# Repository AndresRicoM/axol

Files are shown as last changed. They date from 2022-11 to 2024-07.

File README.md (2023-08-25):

<div align="center">
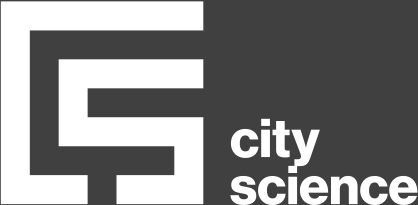
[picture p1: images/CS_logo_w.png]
      
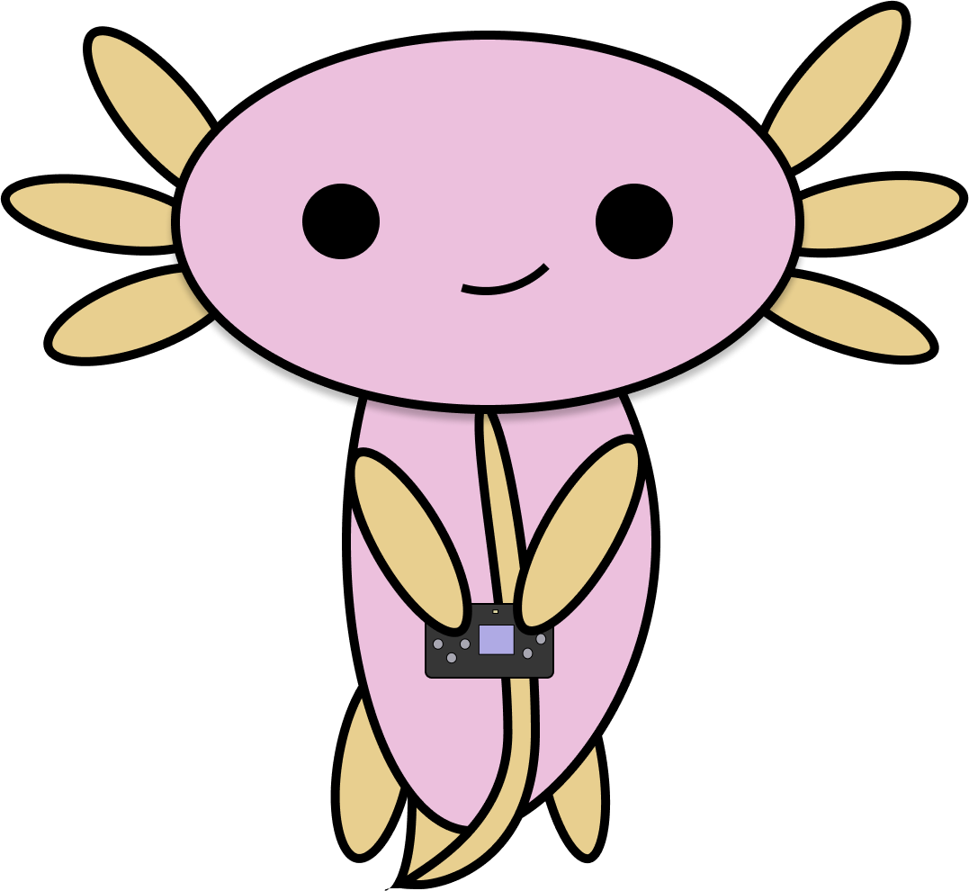
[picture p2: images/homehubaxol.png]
      <br>
      <a href="https://github.com/AndresRicoM/axol/blob/main/LICENSE.MD">
            
      </a>

</div><br><br><br>

<h1> axol </h1>

Sensors for granular assessment of water usage patterns in informal settlements.

This repository contains all files needed to replicate a fully functional Axol sensing system.

The current version of the system is has four sensor types and a HomeHub communication device. The four sensing units include tank sensors, bucket sensors, quality sensors and environmental sensors.

Andres Rico - MIT Media Lab - <aricom@mit.edu>

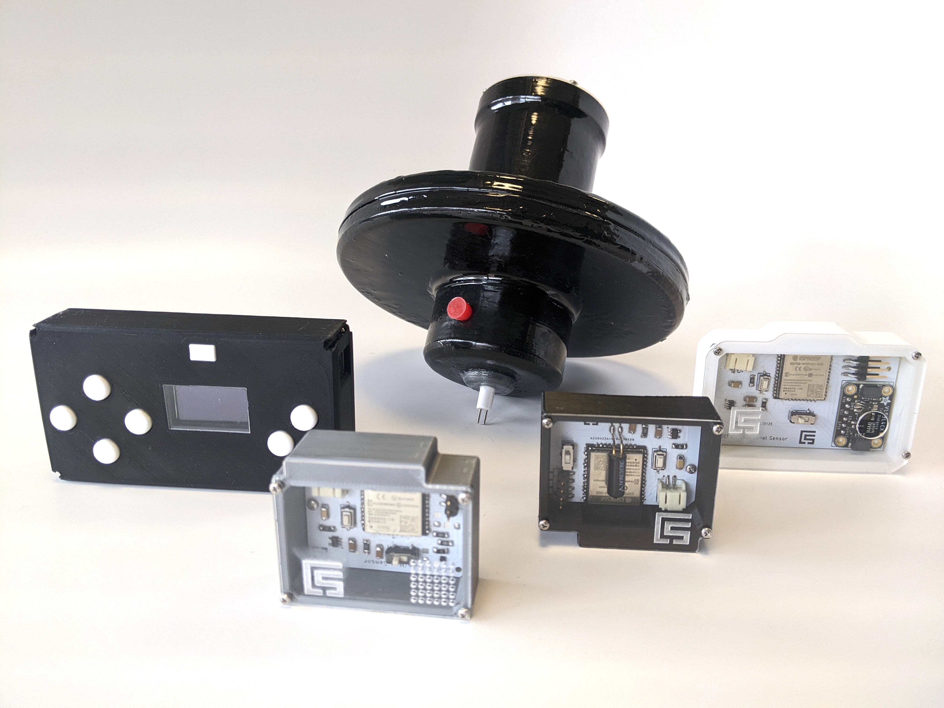
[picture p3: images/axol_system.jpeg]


<h1>Devices</h1>

<h2><a href="https://github.com/AndresRicoM/axol/tree/main/homehub">HomeHub</a></h2>
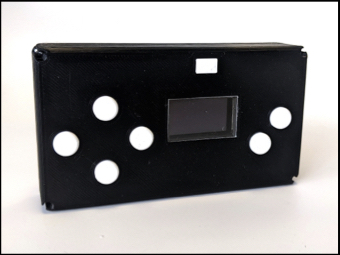
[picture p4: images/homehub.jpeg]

The HomeHub acts as a user interface and as the centralized data relay for the system. All of the sensing units send the data directly to a HomeHub. The HomeHub formats and sends the infroamtion to a remote database. 

Note: It is advised to firstly manufacture a HomeHub device as all other sensors directly connect to the HomeHub. 

<h2><a href="https://github.com/AndresRicoM/axol/tree/main/sensors/tank_sensor">Tank Sensor</a></h2>

<p align="left">
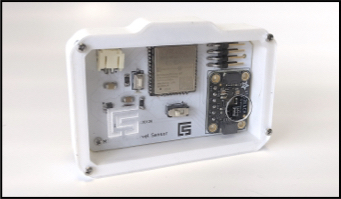
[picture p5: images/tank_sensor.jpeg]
      
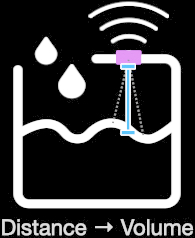
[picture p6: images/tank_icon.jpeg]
      
</p>

The tank sensor uses Adafruits VXL ToF distance sensor. It measures the distance between a water tanks lid and the water line. With this information we can calculate a containers used volume to detemrine how much water is stored within the container. 

<h2><a href="https://github.com/AndresRicoM/axol/tree/main/sensors/bucket_sensor">Bucket Sensor</a></h2>
<p align="left">
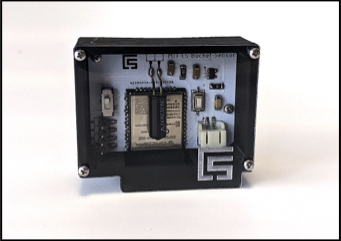
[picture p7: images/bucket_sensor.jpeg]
      
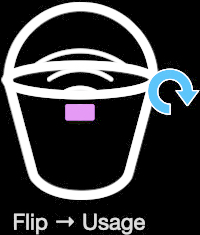
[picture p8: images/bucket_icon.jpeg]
      
</p>

The bucket sensor uses a simple tilt switch. The switch is closed whenever a bucket is flipped. Everytime that the switch is activated, the sensor sends a notice to the HomeHub and the HomeHub timestamps the information before sending it to the database. 

<h2><a href="https://github.com/AndresRicoM/axol/tree/main/sensors/water_quality_sensor">Quality Sensor</a></h2>

<p align="left">
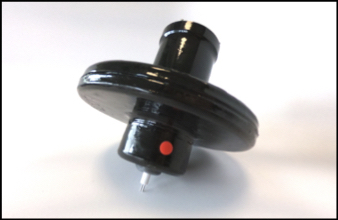
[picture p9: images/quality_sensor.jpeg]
      
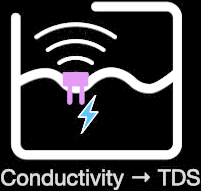
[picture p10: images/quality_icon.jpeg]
      
</p>

The quality sensor measures EC in water to get an estimate of Total Dissolved Solids. 

<h2>Environmental Sensor</h2>
The environmental sensor uses an STH sensor to measure enviroenmental temperature and humidity. The sensor can be a good way to evaluate system and battery performance. It can also be used to track environemetal variables of places were the other sensors are placed. 

<h1>Programming Devices</h1>

Devices can be easily programmed using the [Arduino IDE](https://www.arduino.cc/en/software). You will need to make sure that you have the Espressif [ESP32 core](https://github.com/espressif/arduino-esp32) installed along with all required libraries. 

We need a [USB-TTL adapter](https://duckduckgo.com/?q=USB-TTL+adapter&atb=v313-1&iax=images&ia=images) to program the sensor. 

- Connect Cables as Follows:

```
Device - Adapter
V+   ------ 3.3V (or 5V)
GND  ------ GND
TX   ------ RX
RX   ------ TX
```

NOTE: MAKE SURE TO DISCONNECT ANY POWER SUPPLY. THE BOARD SHOULD ONLY BE POWERED BY THE ADAPTER CABLES. 
NOTE: EACH DEVICE HAS A DIFFERENT PIN ORDER, REFERENCE EACH DEVICE'S PIN DIAGRAM TO MAKE SURE YOU ARE CONNECTING PINS CORRECTLY. 

- Once connection is done, open your serial monitor at a 115200 baud rate, click the reset button on the device and verify that you see inforamtion. 
- Set ESP to Boot Mode. To set the device on bootmode, press the reset button
- Upload sketch 
- Reset device. Toggle switch to opposite position and presss the reset button. 

<h1>Device Registration</h1>

Each device needs to be individually registered. You can register all devices [here](http://blindspot.media.mit.edu/homehubweb/registration.html). 

All sensors must be paired with a HomeHub that has been previously registered. 

<h1>Querying Data</h1>

All system data can be queried through available [API calls](https://github.com/AndresRicoM/axol/wiki/API-Documentation). The calls allow you to get information on network status as well as to access all data for all registered sensors. You will need to firstly register a HomeHub as your HomeHub's Mac Add will act as your key to access all of your systems data.

<h1>Viewing your system's data </h1>

All sensors send their information to the HomeHub, the HomeHub then sends it into a database for storage, calculation of water volumes and consumption and visualization. 

You can check your systems data [here](http://blindspot.media.mit.edu/homehubweb/status_check.html)
By just typing in your HomeHubs registered MAC address. 

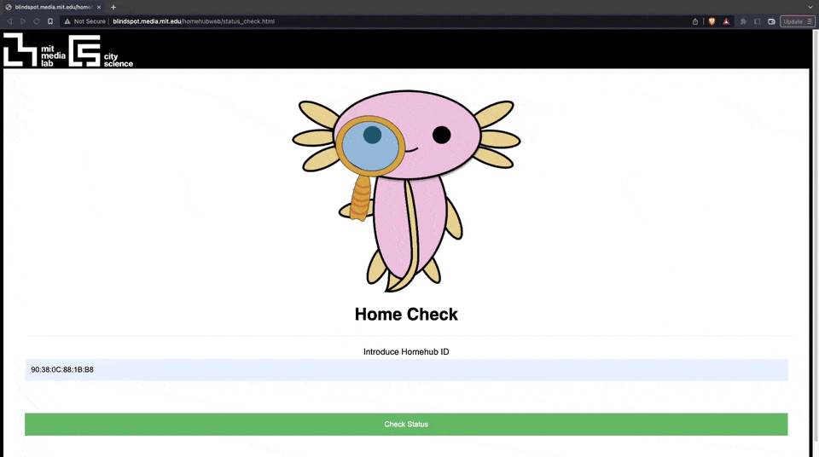
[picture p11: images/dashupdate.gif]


NOTE: ONLY REGISTERED HOMEHUBS WILL ALLOW TO SEE DATA IN THIS DASHBOARD

<h1>Data handling</h1>

The system uses the HomeHub to send data to a server hosted @MIT. All of the data of registered devices is accessible by the developers of the platform. If you do not want developers to have access you will need to build backend infrstructure that will allow you to save data in a different server and modify the 
   connect_send() 
   get_system_stats()
   server_send() 
   
function in the HomeHub's <a href="https://github.com/AndresRicoM/axol/blob/main/homehub/code/cs_homehub.ino">code</a>.

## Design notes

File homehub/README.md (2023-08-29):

# AXOL

```
   █████╗ ██╗  ██╗ ██████╗ ██╗     
  ██╔══██╗╚██╗██╔╝██╔═══██╗██║     
  ███████║ ╚███╔╝ ██║   ██║██║     
  ██╔══██║ ██╔██╗ ██║   ██║██║     
  ██║  ██║██╔╝ ██╗╚██████╔╝███████╗
  ╚═╝  ╚═╝╚═╝  ╚═╝ ╚═════╝ ╚══════╝

  ᓬ(• - •)ᕒ

Andres Rico - MIT Media Lab - <aricom@mit.edu>

```

<h1>Homehub </h1>

<h2>Program Set-up</h2>
You will need to add your wifi credentials to the program. The device needs an SSID and a password. If the network is open. You can leave the password as an emptu string. 
Modify the following lines:

```
  //WIFI Variables
  const char* ssid = ""; //Change accordingly to connect to a WIFi network.
  const char* password = "";

```

You will also need to add your OpenWeather API key. If you do not have one, you can get a free key [here](https://openweathermap.org/api).
Add yout key in the following line:

```
  In the 

  get_complete_weather()

  fucntion, modify line:

  //Open Weather API Key
  const String key = "{Your Open Weather API Key}";

```

After modifying these lines, you are ready to upload the program to your device.

<h2>Bill Of Materials</h2>

```
quantity - component - estimated price

1 - ESP32-WROOM-32E-H4 - $3.15
1 - Switch (JS102011JCQN) - $0.65
1 - Button (PTS636 SM25F SMTR LFS) - $0.14140
1 - 0.1 uF Capacitor (C1206C104KARAC7800) - $0.14880	
1 - 1uF Capacitor (C3216X7R1H105K160AB) - $0.09680	
1 - 10uF Capacitor (GRT31CC8YA106ME01L) - $0.20060	
1 - Gikfun Metal Ball Tilt Shaking Position Switches - $0.399
1 - 500 mAh Lipo Battery 1578 - $7.95000	
1 - Battery Connector (S2B-PH-SM4-TB(LF)(SN)) - $0.41040	
1 - 3.3V Voltage Regulator (RT9080-33GJ5) - $0.25780	
1 - 4 POS Headers (GBC36SGSN-M89) - $0.47
1 - 10K Ohm Resistor (RC1206FR-0710KL) - $0.02

```

<h2>PCB Diagram</h2>

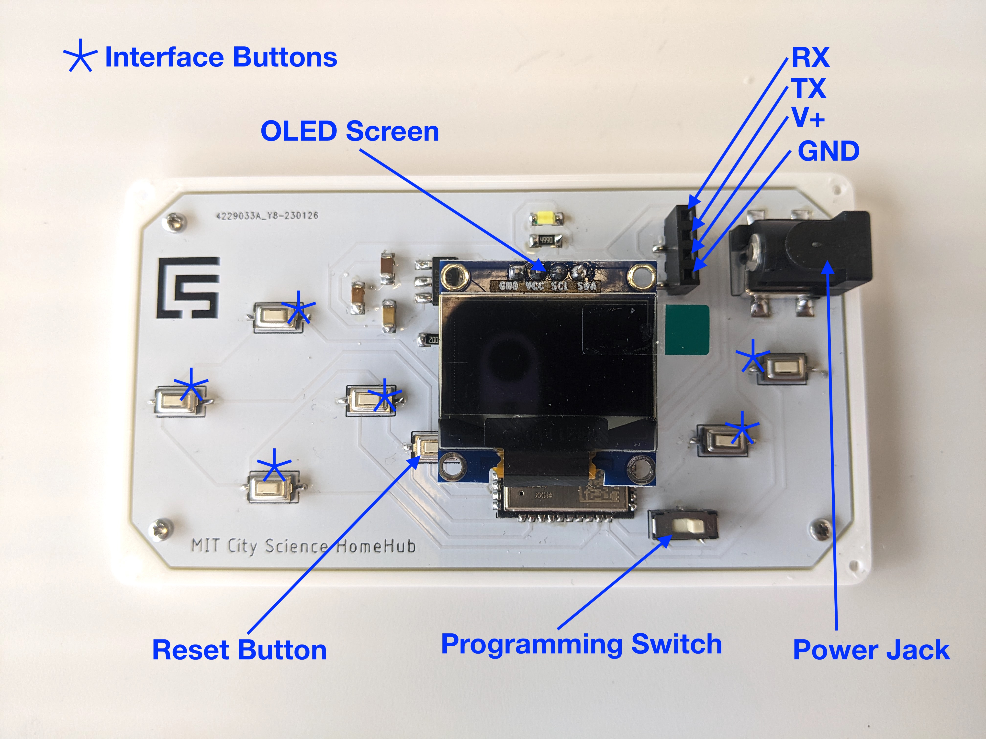
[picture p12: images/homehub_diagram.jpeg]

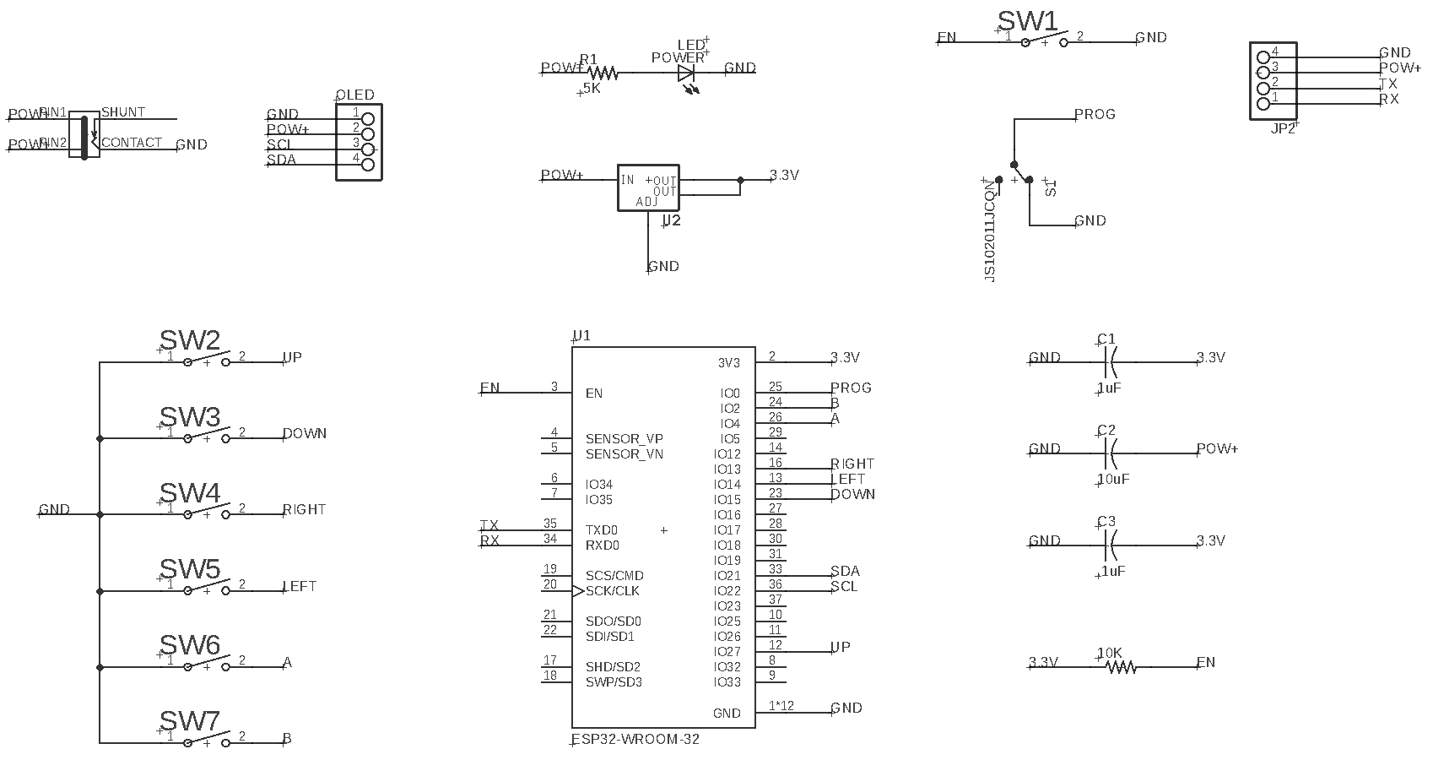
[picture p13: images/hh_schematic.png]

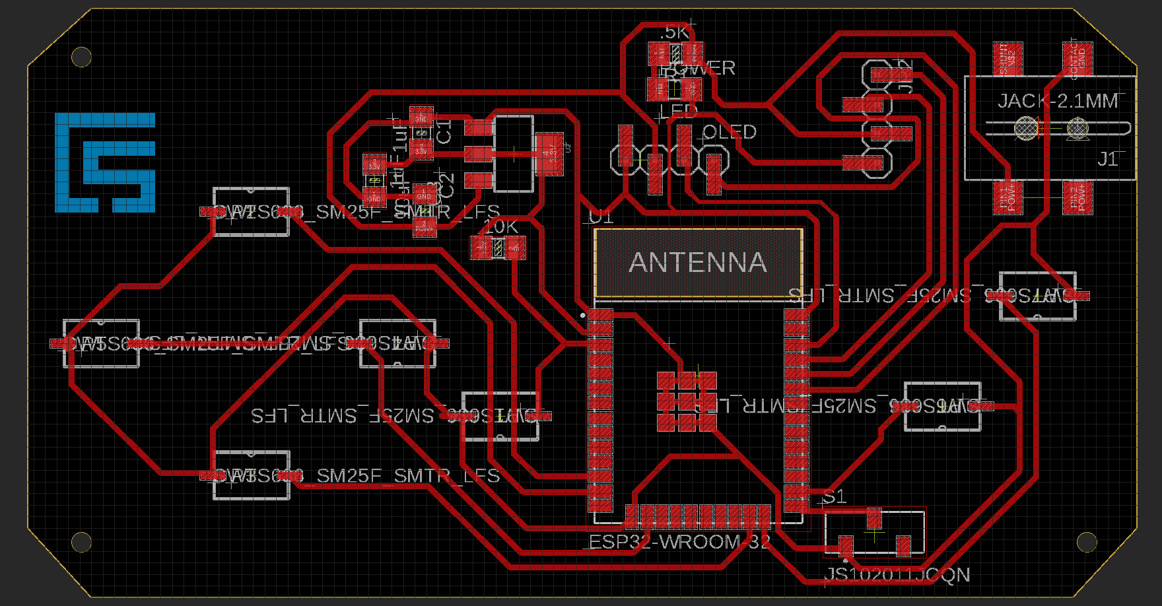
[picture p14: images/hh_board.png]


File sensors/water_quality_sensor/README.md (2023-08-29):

# AXOL

```
   █████╗ ██╗  ██╗ ██████╗ ██╗     
  ██╔══██╗╚██╗██╔╝██╔═══██╗██║     
  ███████║ ╚███╔╝ ██║   ██║██║     
  ██╔══██║ ██╔██╗ ██║   ██║██║     
  ██║  ██║██╔╝ ██╗╚██████╔╝███████╗
  ╚═╝  ╚═╝╚═╝  ╚═╝ ╚═════╝ ╚══════╝

  ᓬ(• - •)ᕒ

Andres Rico - MIT Media Lab - <aricom@mit.edu>

```

<h1>Quality Sensor </h1>

<h2>Program Set-up</h2>

You will need to add your wifi credentials to the program. The device only needs an SSID for esp32 to activate. You do not need a password. Make sure that the SSID provided is the same as the one provided to you HomeHub. The devices need to be connected to the same network. To add SSID modify the following line:

```
  constexpr char WIFI_SSID[] = ""; //Network name, no password required.

```

You will also need to add the mac address of the HomeHub that the sensor will send its data to. To add the mac address modify the following line: 

Substitute each 00 pair with the specific digits of the Homehubs mac address.

```
  //Receiver address
  uint8_t broadcastAddress[] = {0x00, 0x00, 0x00, 0x00, 0x00, 0x00}; //MAC Address for receiving homehub.

```

After modifying these lines, you are ready to upload the program to your device.

<h2>Bill Of Materials</h2>

```
quantity - component - estimated price

1 - ESP32-WROOM-32E-H4 - $3.15
1 - Switch (JS102011JCQN) - $0.65
1 - Button (PTS636 SM25F SMTR LFS) - $0.14140
1 - 500 mAh Lipo Battery 1578 - $7.95000	
3 - 10K Ohm Resistor (RC1206FR-0710KL) - $0.02
1 - 7 POS Headers (GBC36SGSN-M89) - $0.8225
2 - 0 Ohm Resistor (RC1206JR-070RL) - $0.02040	
1 - Temp/Hum Sensor (SHT40I-AD1B-R3) - $2.45700	
1 - Battery Connector (S2B-PH-SM4-TB(LF)(SN)) - $0.41040	
1 - KEYESTUDIO TDS Meter Probe Water - $13.99

```

<h2>PCB Diagram</h2>

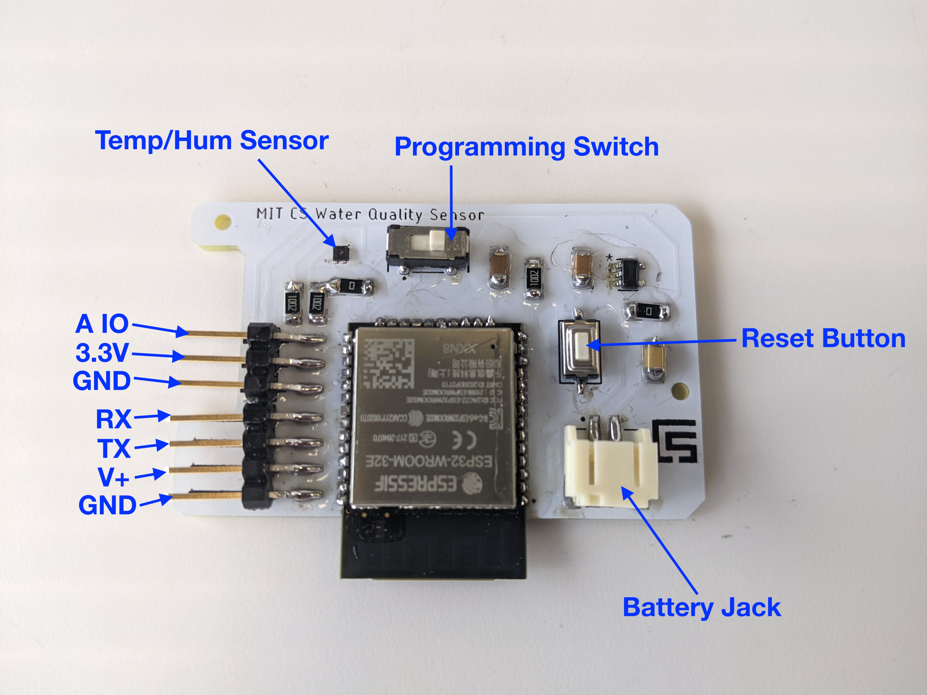
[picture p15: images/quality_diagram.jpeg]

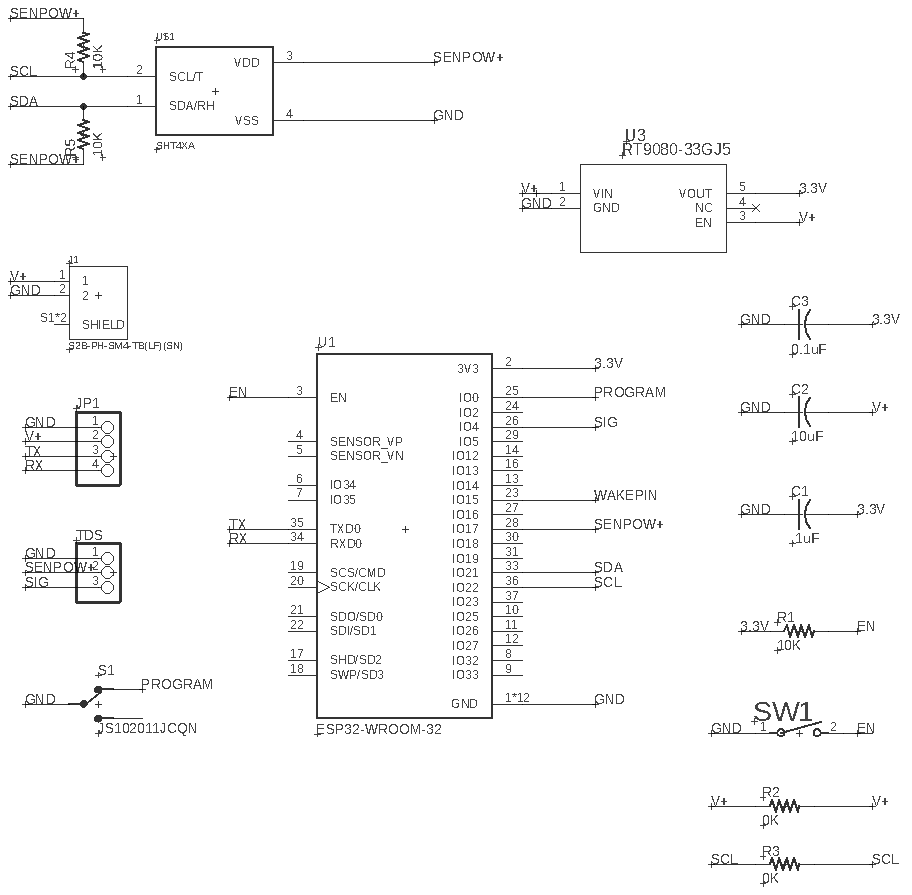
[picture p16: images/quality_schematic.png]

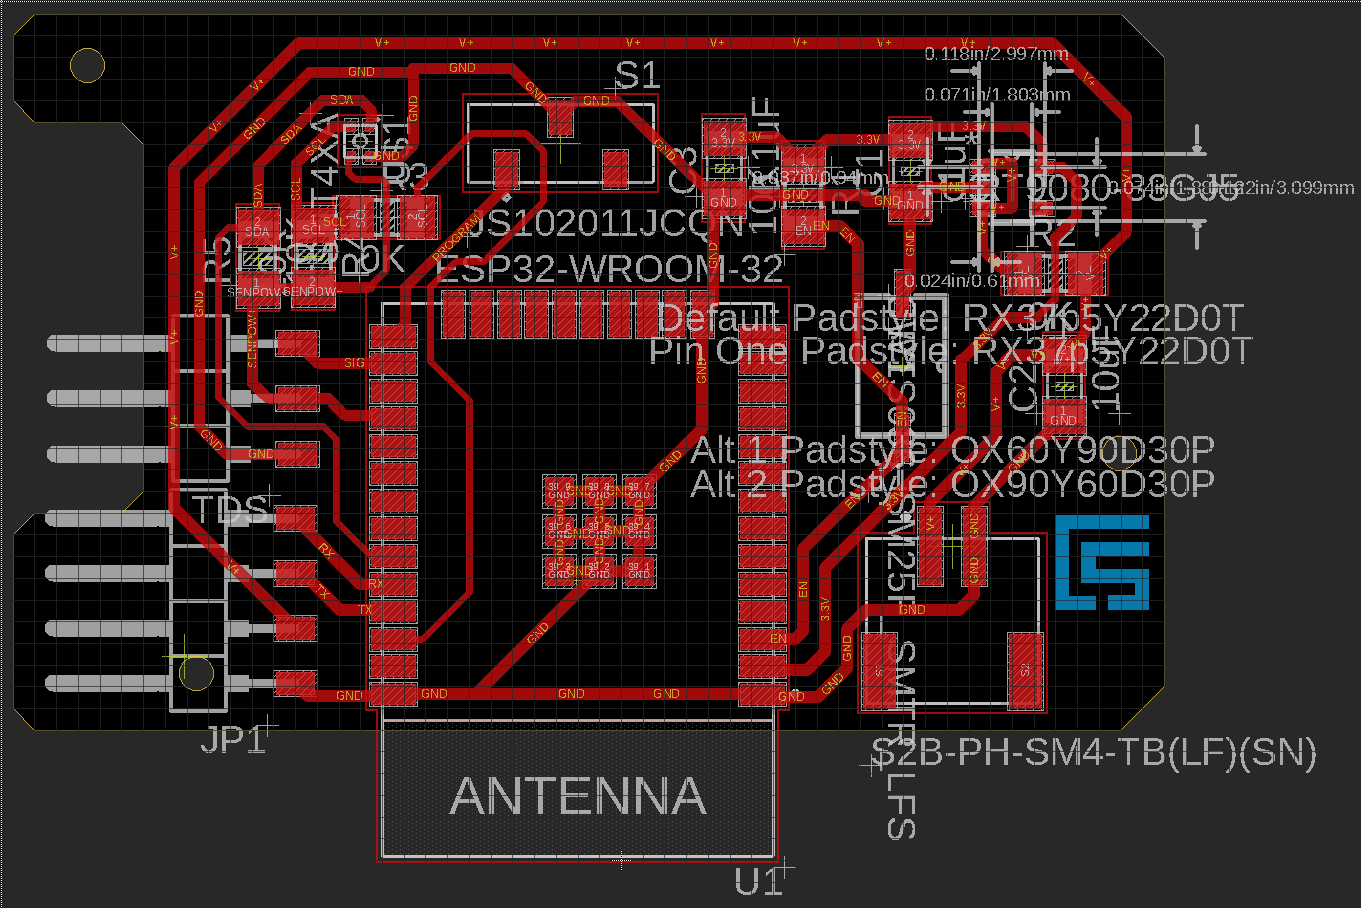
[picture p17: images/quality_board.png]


<h2>Demos</h2>



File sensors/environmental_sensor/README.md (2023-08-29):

# AXOL

```
   █████╗ ██╗  ██╗ ██████╗ ██╗     
  ██╔══██╗╚██╗██╔╝██╔═══██╗██║     
  ███████║ ╚███╔╝ ██║   ██║██║     
  ██╔══██║ ██╔██╗ ██║   ██║██║     
  ██║  ██║██╔╝ ██╗╚██████╔╝███████╗
  ╚═╝  ╚═╝╚═╝  ╚═╝ ╚═════╝ ╚══════╝

  ᓬ(• - •)ᕒ

Andres Rico - MIT Media Lab - <aricom@mit.edu>

```

<h1>Environmental Sensor </h1>

<h2>Program Set-up</h2>

You will need to add your wifi credentials to the program. The device only needs an SSID for esp32 to activate. You do not need a password. Make sure that the SSID provided is the same as the one provided to you HomeHub. The devices need to be connected to the same network. To add SSID modify the following line:

```
  constexpr char WIFI_SSID[] = ""; //Network name, no password required.

```

You will also need to add the mac address of the HomeHub that the sensor will send its data to. To add the mac address modify the following line: 

Substitute each 00 pair with the specific digits of the Homehubs mac address.

```
  //Receiver address
  uint8_t broadcastAddress[] = {0x00, 0x00, 0x00, 0x00, 0x00, 0x00}; //MAC Address for receiving homehub.

```

After modifying these lines, you are ready to upload the program to your device.

<h2>Bill Of Materials</h2>

```
quantity - component - estimated price

1 - ESP32-WROOM-32E-H4 - $3.15
1 - Switch (JS102011JCQN) - $0.65
1 - Button (PTS636 SM25F SMTR LFS) - $0.14140
1 - 500 mAh Lipo Battery 1578 - $7.95000	
1 - Temp/Hum Sensor (SHT40I-AD1B-R3) - $2.45700	
3 - 10K Ohm Resistor (RC1206FR-0710KL) - $0.02
1 - Battery Connector (S2B-PH-SM4-TB(LF)(SN)) - $0.41040	
1 - Temp/Hum Sensor (SHT40I-AD1B-R3) - $2.45700	

```

<h2>PCB Diagram</h2>


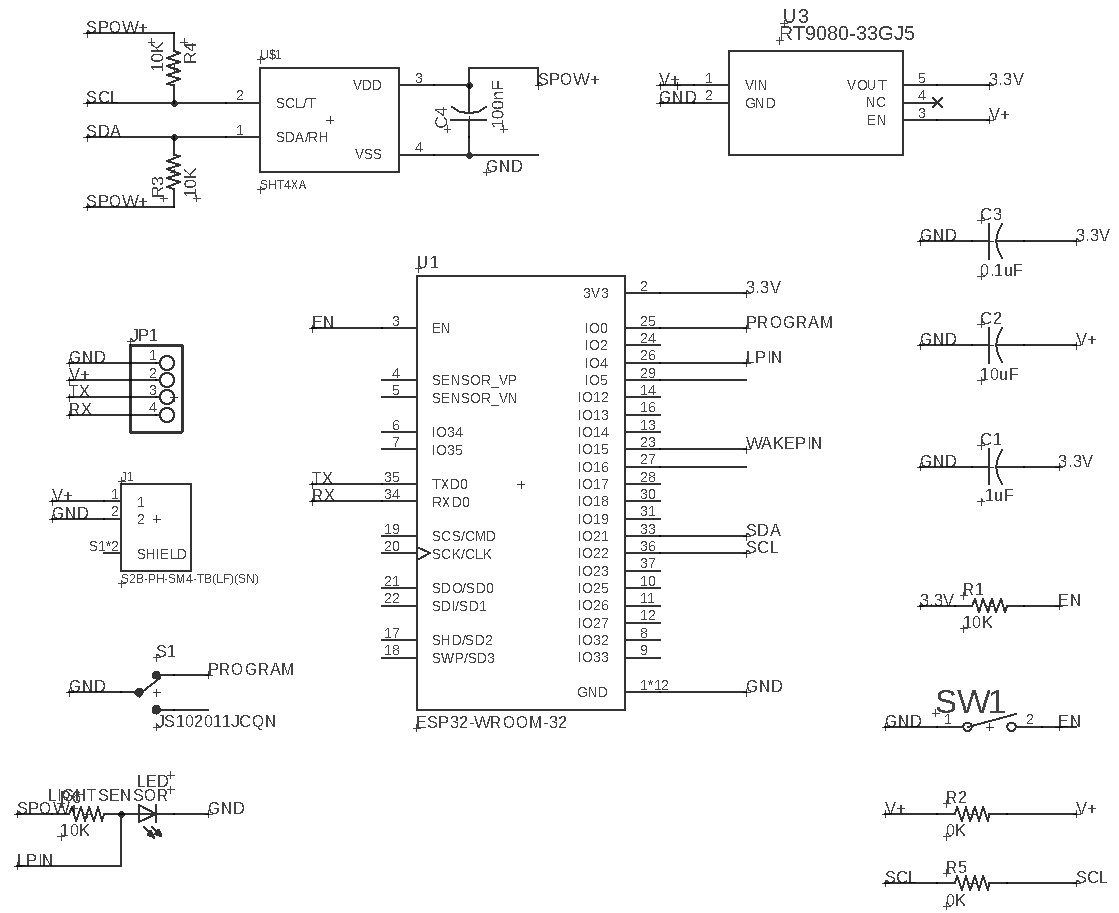
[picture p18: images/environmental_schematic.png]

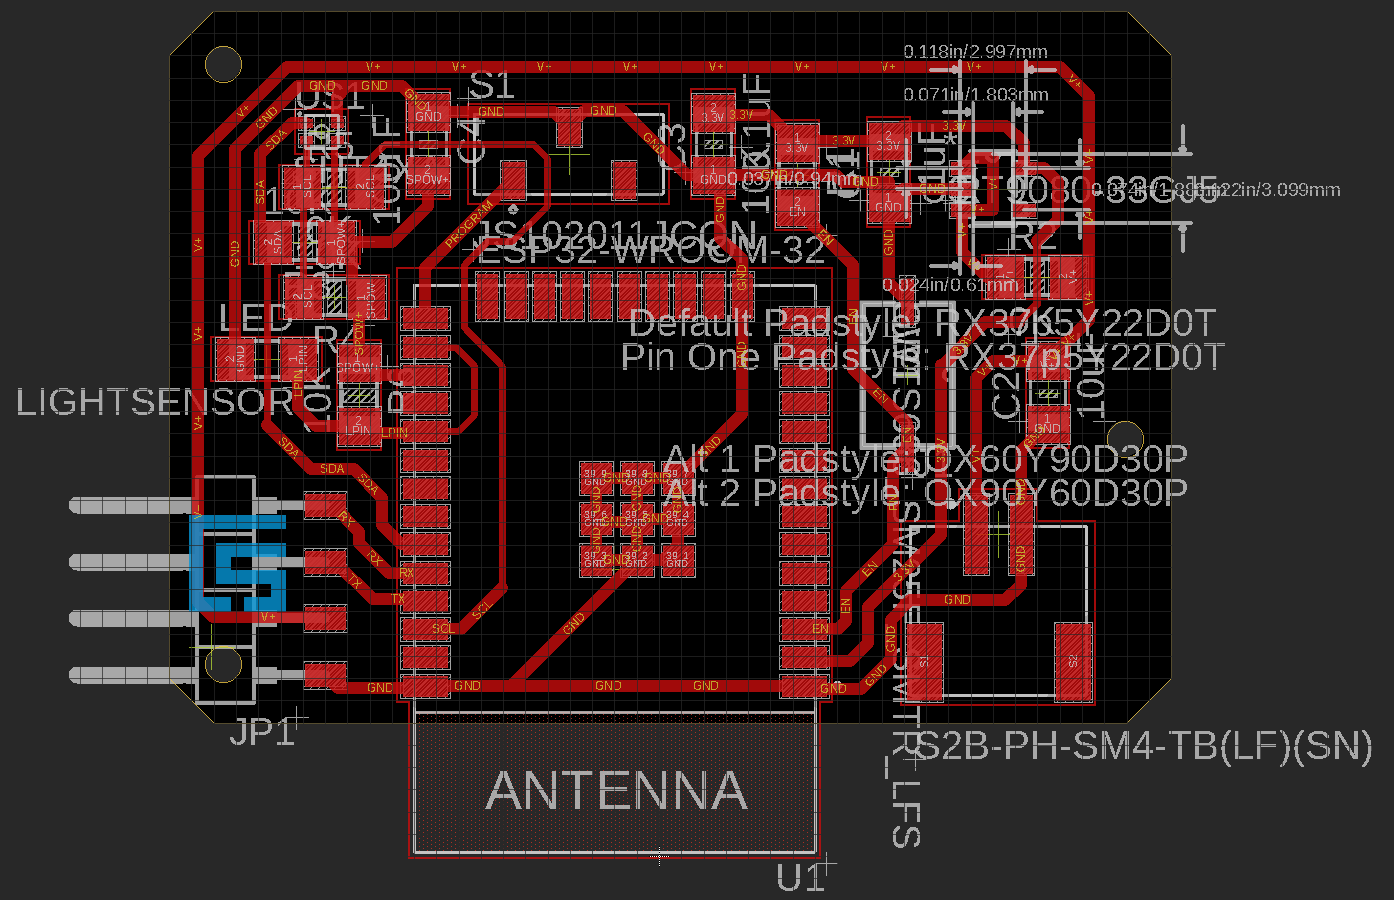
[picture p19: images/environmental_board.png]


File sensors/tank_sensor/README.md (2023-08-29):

# AXOL

```
   █████╗ ██╗  ██╗ ██████╗ ██╗     
  ██╔══██╗╚██╗██╔╝██╔═══██╗██║     
  ███████║ ╚███╔╝ ██║   ██║██║     
  ██╔══██║ ██╔██╗ ██║   ██║██║     
  ██║  ██║██╔╝ ██╗╚██████╔╝███████╗
  ╚═╝  ╚═╝╚═╝  ╚═╝ ╚═════╝ ╚══════╝

  ᓬ(• - •)ᕒ

Andres Rico - MIT Media Lab - <aricom@mit.edu>

```

<h1>Tank Sensor </h1>

<h2>Program Set-up</h2>

You will need to add your wifi credentials to the program. The device only needs an SSID for esp32 to activate. You do not need a password. Make sure that the SSID provided is the same as the one provided to you HomeHub. The devices need to be connected to the same network. To add SSID modify the following line:

```
  constexpr char WIFI_SSID[] = ""; //Network name, no password required.

```

You will also need to add the mac address of the HomeHub that the sensor will send its data to. To add the mac address modify the following line: 

Substitute each 00 pair with the specific digits of the Homehubs mac address.

```
  //Receiver address
  uint8_t broadcastAddress[] = {0x00, 0x00, 0x00, 0x00, 0x00, 0x00}; //MAC Address for receiving homehub.

```

After modifying these lines, you are ready to upload the program to your device.

<h2>Bill Of Materials</h2>

```
quantity - component - estimated price

1 - ESP32-WROOM-32E-H4 - $3.15
1 - Switch (JS102011JCQN) - $0.65
1 - Button (PTS636 SM25F SMTR LFS) - $0.14140
1 - 500 mAh Lipo Battery 1578 - $7.95000	
1 - 10K Ohm Resistor (RC1206FR-0710KL) - $0.02
1 - 0 Ohm Resistor (RC1206JR-070RL) - $0.02040	
1 - 4 POS Headers (GBC36SGSN-M89) - $0.47
1 - 3.3V Voltage Regulator (RT9080-33GJ5) - $0.25780	
1 - 0.1 uF Capacitor (C1206C104KARAC7800) - $0.14880
1 - 1uF Capacitor (C3216X7R1H105K160AB) - $0.09680	
1 - 10uF Capacitor (GRT31CC8YA106ME01L) - $0.20060	
1 - Battery Connector (S2B-PH-SM4-TB(LF)(SN)) - $0.41040	
1 - 4 POS Headers (GBC36SGSN-M89) - $0.47
1 - TOF  Sensor (5425) - $14.95000	

```

<h2>PCB Diagram</h2>

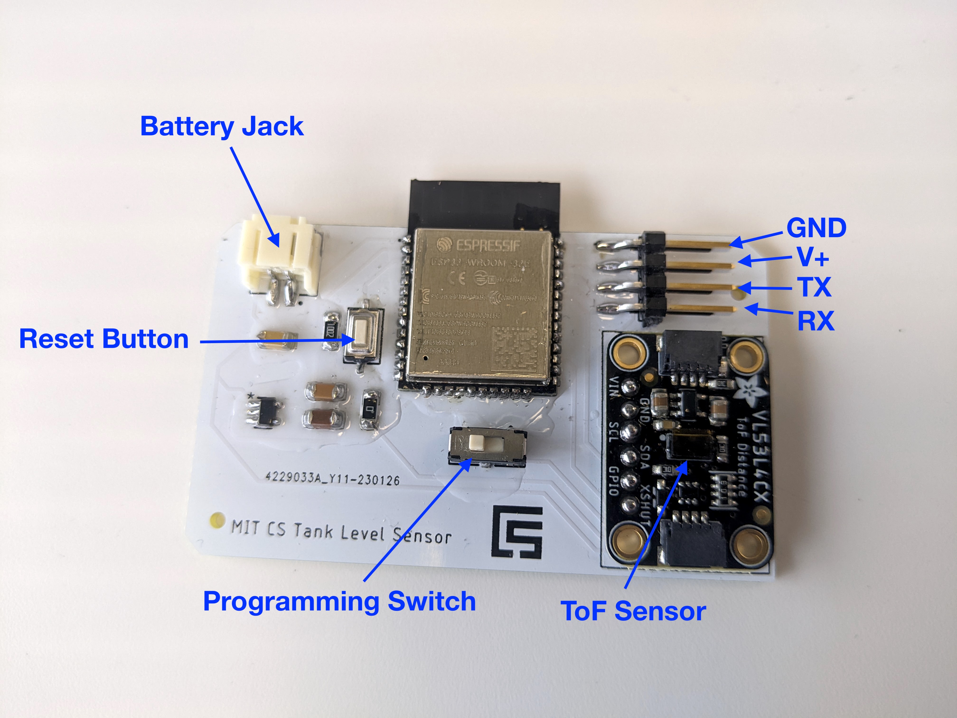
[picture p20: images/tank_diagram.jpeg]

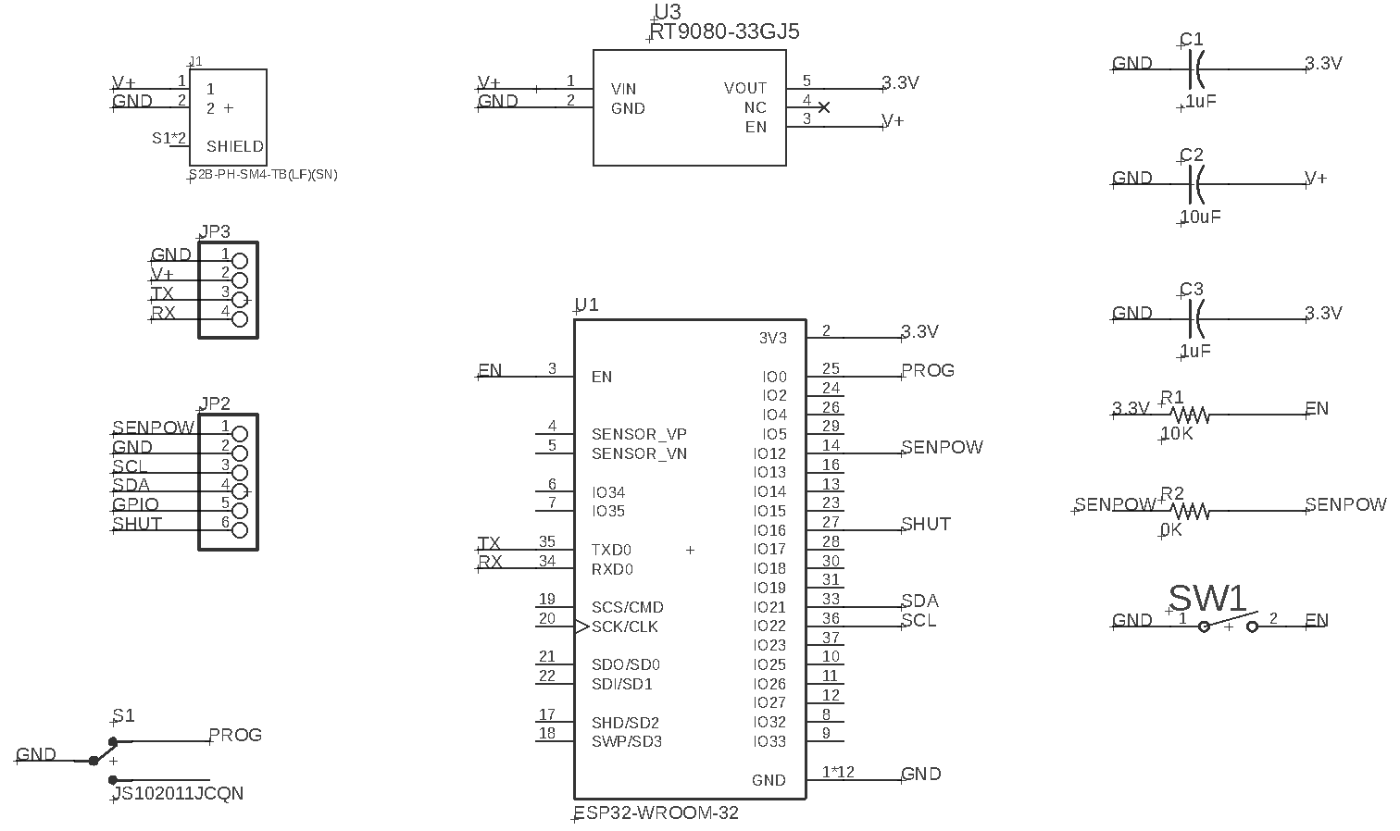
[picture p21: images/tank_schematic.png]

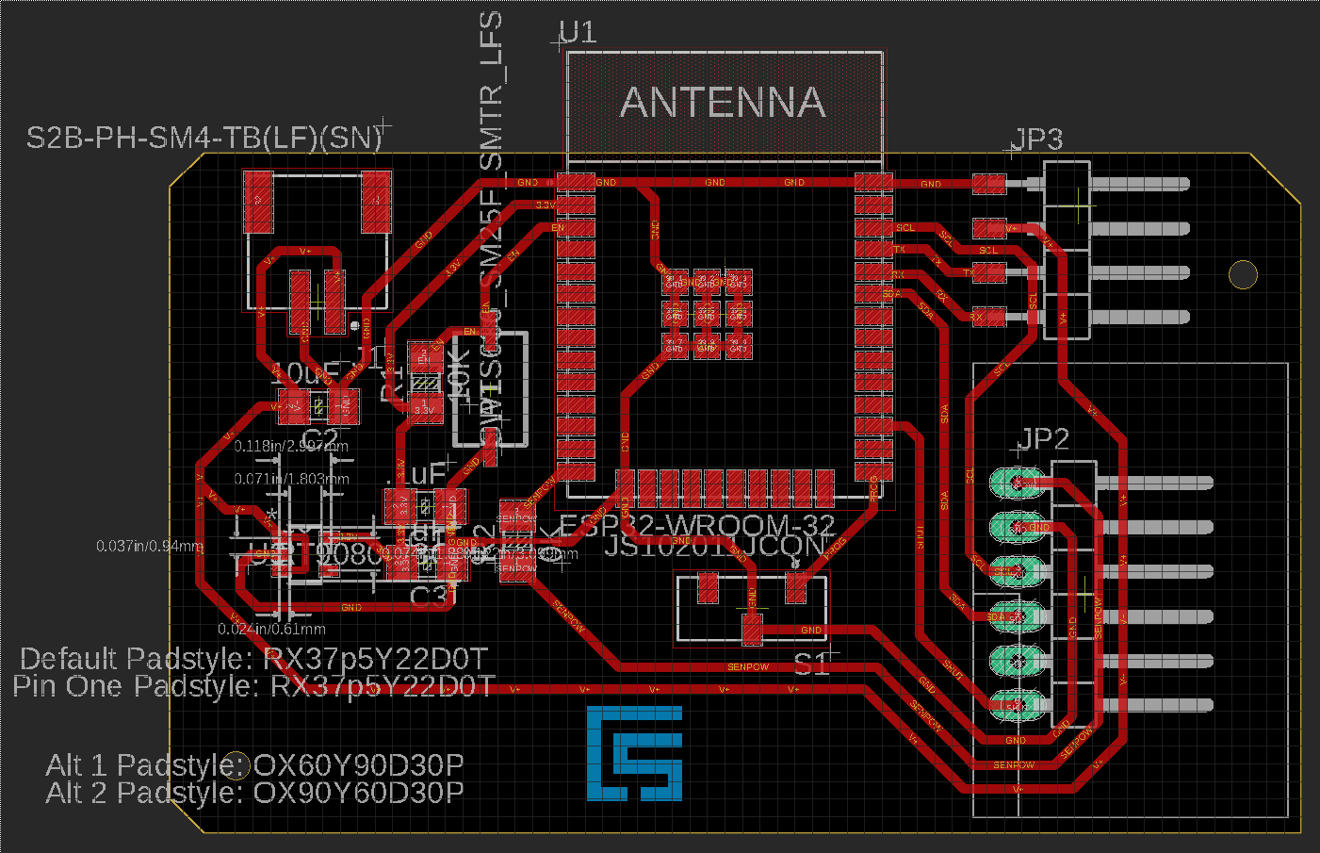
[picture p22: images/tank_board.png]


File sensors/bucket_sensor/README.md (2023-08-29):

# AXOL

```
   █████╗ ██╗  ██╗ ██████╗ ██╗     
  ██╔══██╗╚██╗██╔╝██╔═══██╗██║     
  ███████║ ╚███╔╝ ██║   ██║██║     
  ██╔══██║ ██╔██╗ ██║   ██║██║     
  ██║  ██║██╔╝ ██╗╚██████╔╝███████╗
  ╚═╝  ╚═╝╚═╝  ╚═╝ ╚═════╝ ╚══════╝

  ᓬ(• - •)ᕒ

Andres Rico - MIT Media Lab - <aricom@mit.edu>

```

<h1>Bucket Sensor </h1>

<h2>Program Set-up</h2>

You will need to add your wifi credentials to the program. The device only needs an SSID for esp32 to activate. You do not need a password. Make sure that the SSID provided is the same as the one provided to you HomeHub. The devices need to be connected to the same network. To add SSID modify the following line:

```
  constexpr char WIFI_SSID[] = ""; //Network name, no password required.

```

You will also need to add the mac address of the HomeHub that the sensor will send its data to. To add the mac address modify the following line: 

Substitute each 00 pair with the specific digits of the Homehubs mac address.

```
  //Receiver address
  uint8_t broadcastAddress[] = {0x00, 0x00, 0x00, 0x00, 0x00, 0x00}; //MAC Address for receiving homehub.

```

After modifying these lines, you are ready to upload the program to your device.

<h2>Bill Of Materials</h2>

```
quantity - component - estimated price

1 - ESP32-WROOM-32E-H4 - $3.15
1 - Switch (JS102011JCQN) - $0.65
1 - Button (PTS636 SM25F SMTR LFS) - $0.14140
1 - 0.1 uF Capacitor (C1206C104KARAC7800) - $0.14880	
1 - 1uF Capacitor (C3216X7R1H105K160AB) - $0.09680	
1 - 10uF Capacitor (GRT31CC8YA106ME01L) - $0.20060	
1 - Gikfun Metal Ball Tilt Shaking Position Switches - $0.399
1 - 500 mAh Lipo Battery 1578 - $7.95000	
1 - Battery Connector (S2B-PH-SM4-TB(LF)(SN)) - $0.41040	
1 - 3.3V Voltage Regulator (RT9080-33GJ5) - $0.25780	
1 - 4 POS Headers (GBC36SGSN-M89) - $0.47
1 - 10K Ohm Resistor (RC1206FR-0710KL) - $0.02	

```

<h2>PCB Diagram</h2>


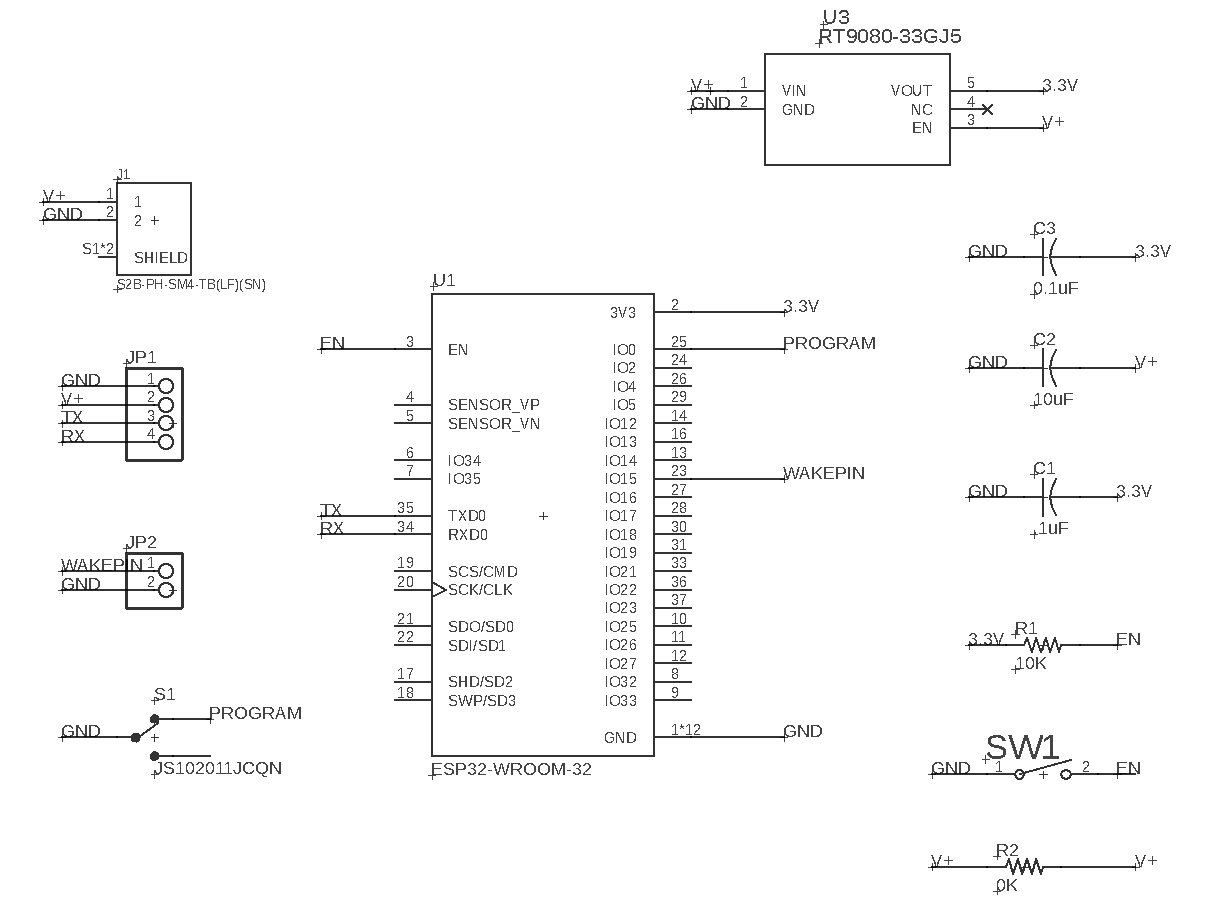
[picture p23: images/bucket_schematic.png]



<h2>Demos</h2>




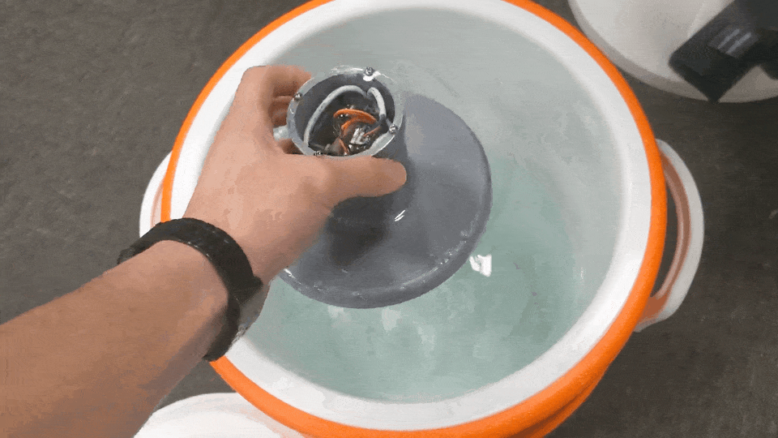
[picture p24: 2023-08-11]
images/buoy_floating.gif

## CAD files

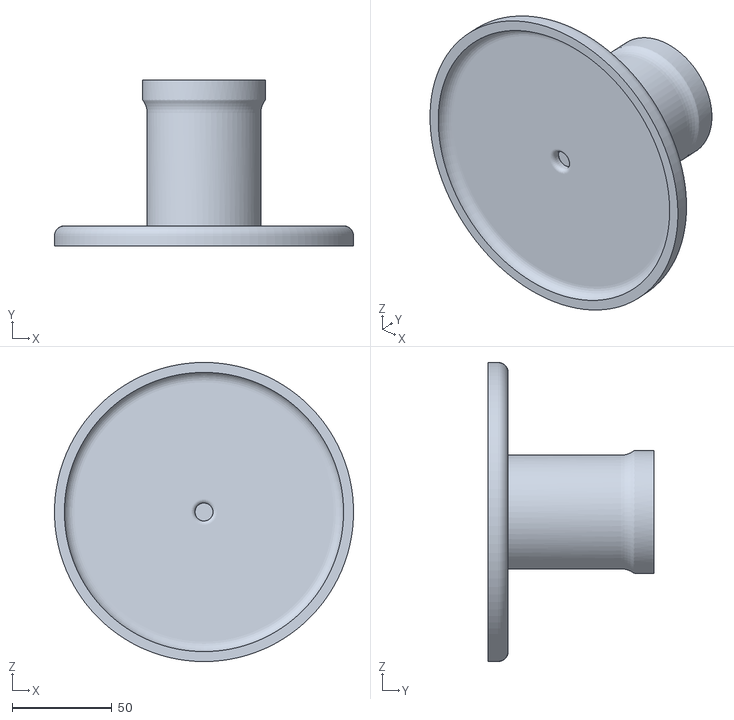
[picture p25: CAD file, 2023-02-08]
sensors/water_quality_sensor/case/buoy_main.stl
149.9 x 83.0 x 150.0

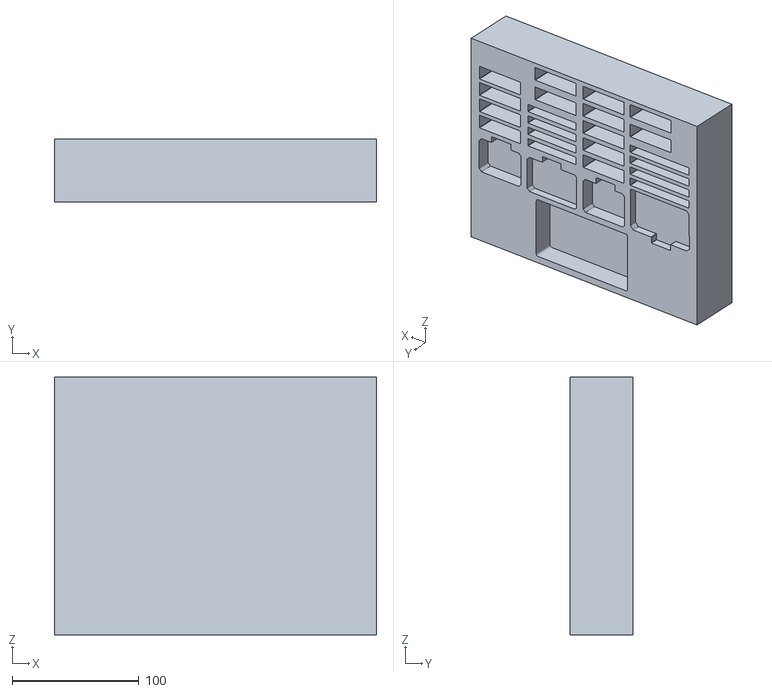
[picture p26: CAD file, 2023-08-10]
deployment/travel_packaging_fab/packaging.stl
254.0 x 50.0 x 203.2

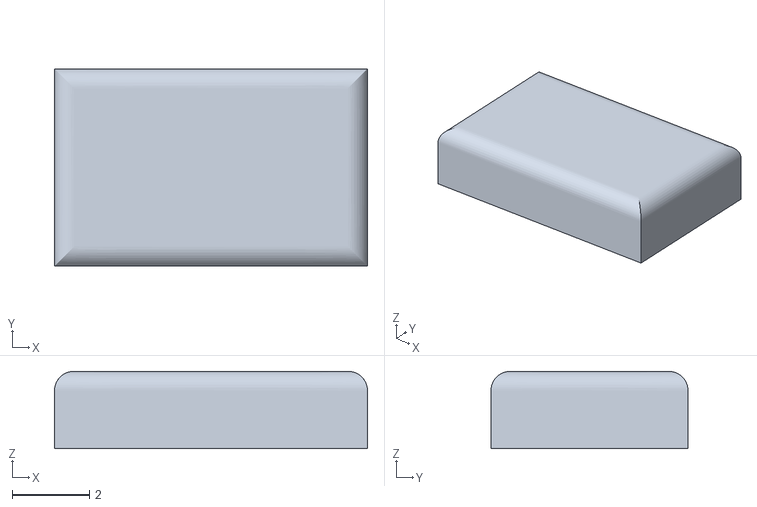
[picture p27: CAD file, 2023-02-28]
homehub/case/LED_Diffuser.stl
8.10 x 5.10 x 2.00

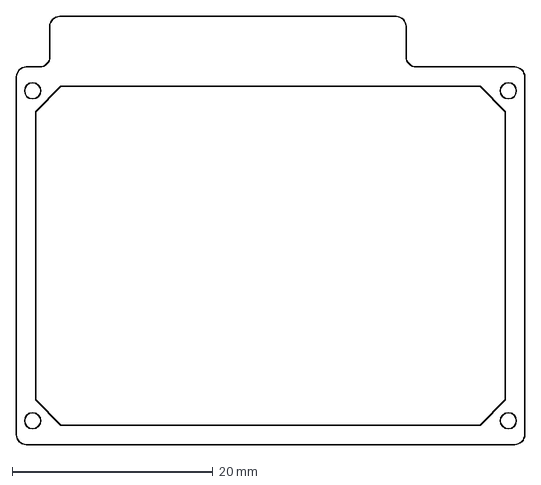
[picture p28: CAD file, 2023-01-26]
sensors/bucket_sensor/case/bucket_lid.dxf
50.6 x 42.6 mm

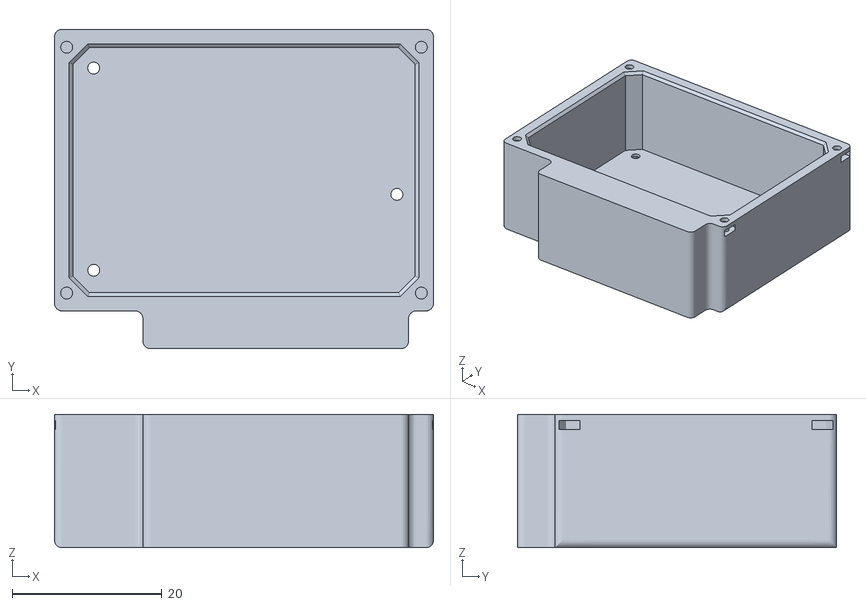
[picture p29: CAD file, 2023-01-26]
sensors/environmental_sensor/case/env_case.stl
50.6 x 42.6 x 17.8

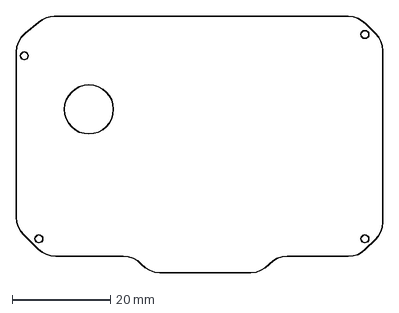
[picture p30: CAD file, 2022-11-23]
sensors/tank_sensor/case/TankCover.dxf
74.7 x 52.3 mm

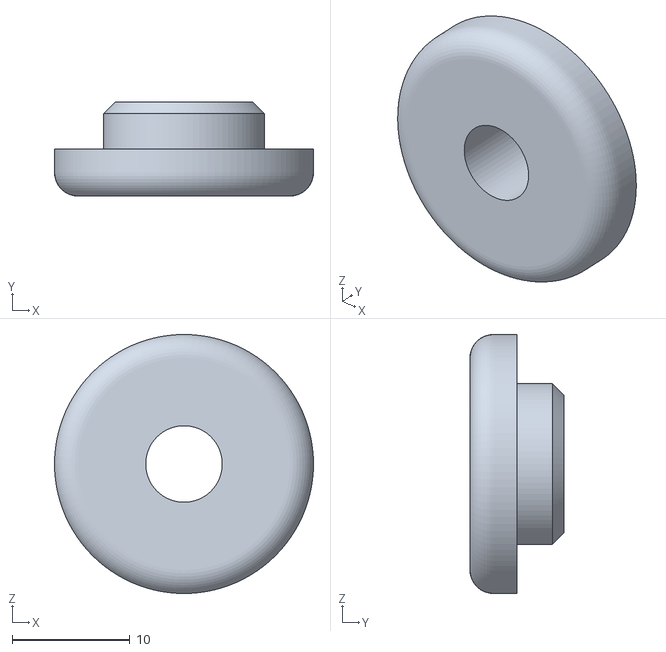
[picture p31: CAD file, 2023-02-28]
sensors/water_quality_sensor/case/buoy_lid_short.stl
22.0 x 8.00 x 22.0

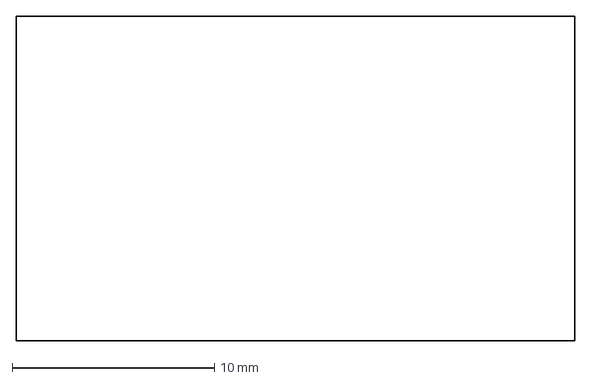
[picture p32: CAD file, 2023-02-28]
homehub/case/hh_case_screen.dxf
27.6 x 16.1 mm

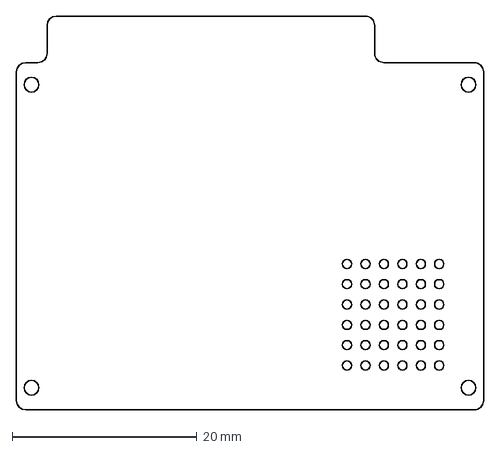
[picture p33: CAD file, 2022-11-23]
sensors/environmental_sensor/case/temp_hum_lid.dxf
50.6 x 42.6 mm

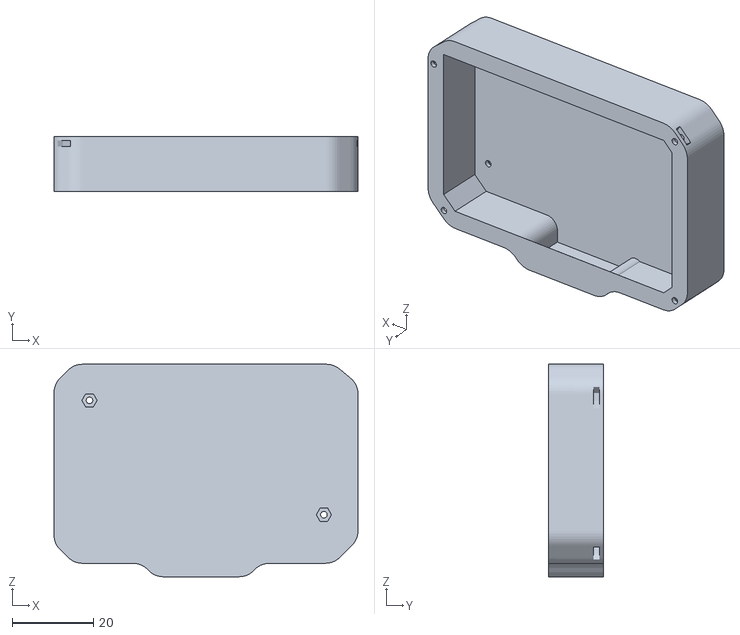
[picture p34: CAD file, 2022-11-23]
sensors/tank_sensor/case/tank_case.stl
74.7 x 13.5 x 52.3

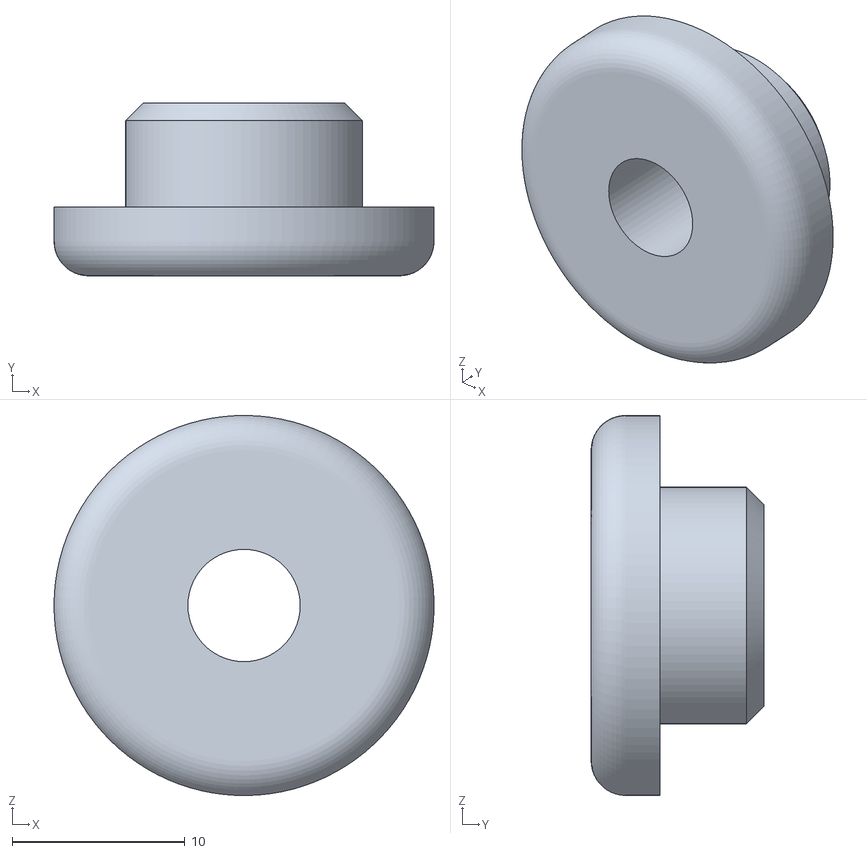
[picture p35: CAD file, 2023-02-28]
sensors/water_quality_sensor/case/buoy_plug.stl
22.0 x 10.0 x 22.0

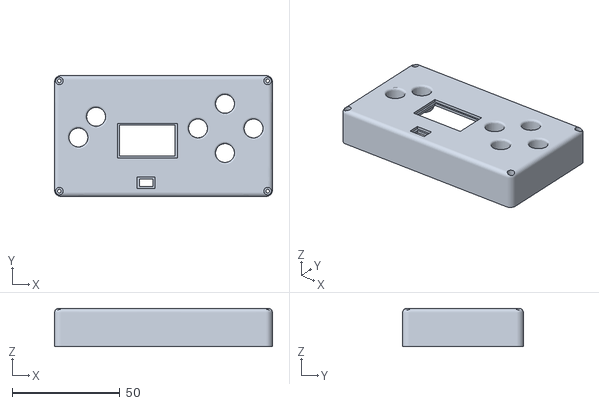
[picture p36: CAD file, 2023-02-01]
homehub/case/hhcase.stl
101.0 x 56.0 x 17.8

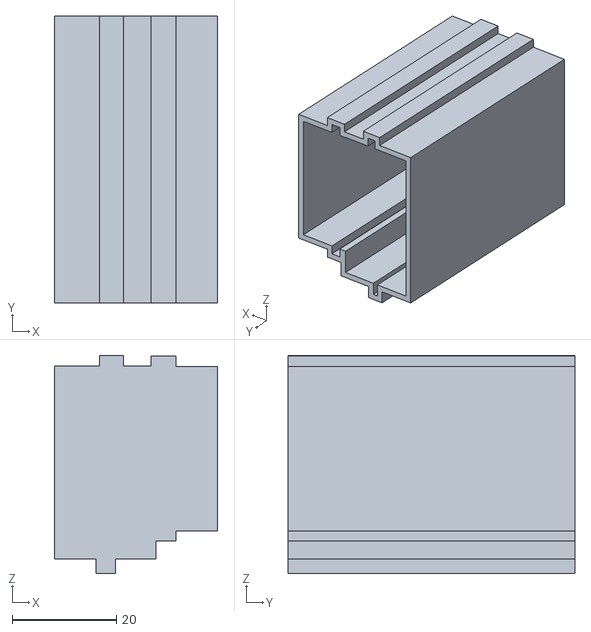
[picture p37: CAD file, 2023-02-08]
sensors/water_quality_sensor/case/buoy_pcb_tray.stl
31.3 x 55.0 x 41.8

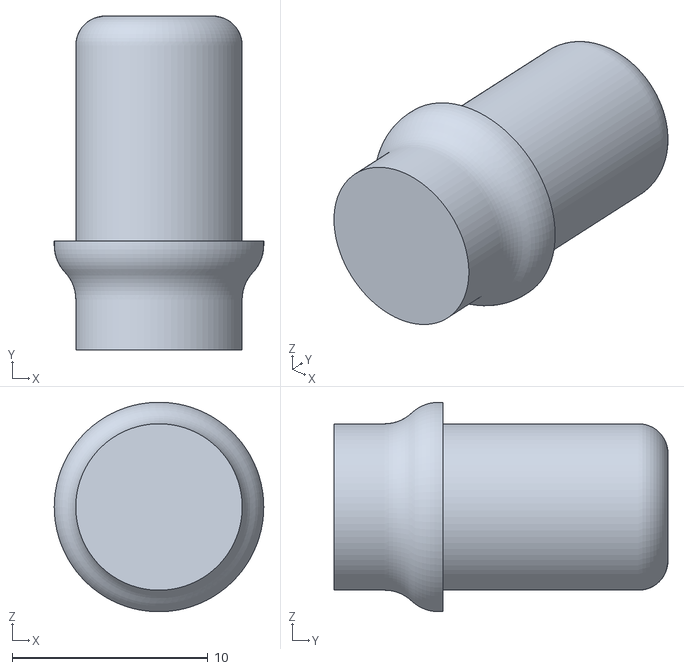
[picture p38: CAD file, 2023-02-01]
homehub/case/button.stl
10.7 x 17.1 x 10.7

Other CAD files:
sensors/bucket_sensor/case/bucket_case.stl
sensors/water_quality_sensor/case/buoy_air_cavity.stl
homehub/case/hh_lid.stl
sensors/water_quality_sensor/case/buoy_lid.dxf
sensors/water_quality_sensor/case/buoy_balast.stl

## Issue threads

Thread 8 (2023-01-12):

quality sensor with surface temperature cannot be rebooted with tds sensor connected.

AndresRicoM, 2023-01-12:
Need to unplug the tds sensor, press reboot button and connect sensor for normal operation. Sensor does not leave pin floating for reboot. Need to connect to another GPIO.

AndresRicoM, 2024-10-31:
Problem was specific to a malfunctioning board.

Closed 2024-10-31.

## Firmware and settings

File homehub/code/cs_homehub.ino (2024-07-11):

/*
  
   █████╗ ██╗  ██╗ ██████╗ ██╗     
  ██╔══██╗╚██╗██╔╝██╔═══██╗██║     
  ███████║ ╚███╔╝ ██║   ██║██║     
  ██╔══██║ ██╔██╗ ██║   ██║██║     
  ██║  ██║██╔╝ ██╗╚██████╔╝███████╗
  ╚═╝  ╚═╝╚═╝  ╚═╝ ╚═════╝ ╚══════╝

  ᓬ(• - •)ᕒ 
           
  Axol sensing system. 

   Code for Homehub Firmware. HomeHub connects to a mesh of sensors and serves as a relay for data coming to and from the sensor system. 
   The device has a built in OLED screen for data visualization. 
   
   Andres Rico - aricom@mit.edu
  
 */

#include <WiFi.h>
#include <Wire.h>
#include <SPI.h>
#include <HTTPClient.h>
#include <ArduinoJson.h>
#include <Adafruit_SSD1306.h>
#include <Adafruit_GFX.h>
#include <esp_now.h>
#include <AsyncTCP.h>
#include <ESPAsyncWebServer.h>
#include "time.h"

//Screen Variables
#define SCREEN_WIDTH 128 // OLED display width, in pixels
#define SCREEN_HEIGHT 64 // OLED display height, in pixels

// Declaration for an SSD1306 display connected to I2C (SDA, SCL pins)
#define OLED_RESET     -1 // Reset pin # (or -1 if sharing Arduino reset pin)
Adafruit_SSD1306 display(SCREEN_WIDTH, SCREEN_HEIGHT, &Wire, OLED_RESET);

#define LOGO_HEIGHT   60  //CS logo Size in pixels
#define LOGO_WIDTH    60

#define WWIDTH  21  //Water Drop Size in pixels
#define WHEIGHT 30

static const unsigned char PROGMEM cs_logo_bmp[] =
{
  B00000000, B00000000, B00000000, B00000000, B00000000, B00000000, B00000000, B00000000,
  B00000000, B00000000, B00000000, B00000000, B00000000, B00000000, B00000000, B00000000,
  B00000000, B00000000, B00000000, B00000000, B00000000, B00000000, B00000000, B00000000,
  B00011111, B11111111, B11111111, B11111111, B11111111, B11111111, B11111111, B11000000,
  B00011111, B11111111, B11111111, B11111111, B11111111, B11111111, B11111111, B11000000,
  B00011111, B11111111, B11111111, B11111111, B11111111, B11111111, B11111111, B11000000,
  B00011111, B11111111, B11111111, B11111111, B11111111, B11111111, B11111111, B11000000,
  B00011111, B11111111, B11111111, B11111111, B11111111, B11111111, B11111111, B11000000,
  B00011111, B11111111, B11111111, B11111111, B11111111, B11111111, B11111111, B11000000,
  B00011111, B11111111, B11111111, B11111111, B11111111, B11111111, B11111111, B11000000,
  B00011111, B11000000, B00000000, B00000000, B00000000, B00000000, B00000000, B00000000,
  B00011111, B11000000, B00000000, B00000000, B00000000, B00000000, B00000000, B00000000,
  B00011111, B11000000, B00000000, B00000000, B00000000, B00000000, B00000000, B00000000,
  B00011111, B11000000, B00000000, B00000000, B00000000, B00000000, B00000000, B00000000,
  B00011111, B11000000, B00000000, B00000000, B00000000, B00000000, B00000000, B00000000,
  B00011111, B11000000, B00000000, B00000000, B00000000, B00000000, B00000000, B00000000,
  B00011111, B11000000, B00000000, B00000000, B00000000, B00000000, B00000000, B00000000,
  B00011111, B11000000, B00000000, B00000000, B00000000, B00000000, B00000000, B00000000,
  B00011111, B11000000, B00000000, B00000000, B00000000, B00000000, B00000000, B00000000,
  B00011111, B11000000, B00111111, B11111111, B11111111, B11111111, B11111111, B11000000,
  B00011111, B11000000, B00111111, B11111111, B11111111, B11111111, B11111111, B11000000,
  B00011111, B11000000, B00111111, B11111111, B11111111, B11111111, B11111111, B11000000,
  B00011111, B11000000, B00111111, B11111111, B11111111, B11111111, B11111111, B11000000,
  B00011111, B11000000, B00111111, B11111111, B11111111, B11111111, B11111111, B11000000,
  B00011111, B11000000, B00111111, B11111111, B11111111, B11111111, B11111111, B11000000,
  B00011111, B11000000, B00111111, B11111111, B11111111, B11111111, B11111111, B11000000,
  B00011111, B11000000, B00111111, B11000000, B00000000, B00000000, B00000000, B00000000,
  B00011111, B11000000, B00111111, B11000000, B00000000, B00000000, B00000000, B00000000,
  B00011111, B11000000, B00111111, B11000000, B00000000, B00000000, B00000000, B00000000,
  B00011111, B11000000, B00111111, B11000000, B00000000, B00000000, B00000000, B00000000,
  B00011111, B11000000, B00111111, B11000000, B00000000, B00000000, B00000000, B00000000,
  B00011111, B11000000, B00111111, B11000000, B00000000, B00000000, B00000000, B00000000,
  B00011111, B11000000, B00111111, B11000000, B00000000, B00000000, B00000000, B00000000,
  B00011111, B11000000, B00111111, B11000000, B00000000, B00000000, B00000000, B00000000,
  B00011111, B11000000, B00111111, B11000000, B00000000, B00000000, B00000000, B00000000,
  B00011111, B11000000, B00111111, B11111111, B11111111, B11111111, B11111111, B11000000,
  B00011111, B11000000, B00111111, B11111111, B11111111, B11111111, B11111111, B11000000,
  B00011111, B11000000, B00111111, B11111111, B11111111, B11111111, B11111111, B11000000,
  B00011111, B11000000, B00111111, B11111111, B11111111, B11111111, B11111111, B11000000,
  B00011111, B11000000, B00111111, B11111111, B11111111, B11111111, B11111111, B11000000,
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
};



const unsigned char happy_axol_bmp[] PROGMEM = {
  
  B00000000,B00000000,B11111111,B00000000,B00000000,B00000000,B00000000,B00000000,B00000000,B00000000,B00001111,B11110000,B00000000,B00001111,
  B00000000,B00000000,B11111111,B00000000,B00000000,B00000000,B00000000,B00000000,B00000000,B00000000,B00001111,B11110000,B00000000,B00001111,
  B00000000,B00000000,B11111111,B00000000,B00000000,B00000000,B00000000,B00000000,B00000000,B00000000,B00001111,B11110000,B00000000,B00001111,
  B00000000,B00000000,B11111111,B00000000,B00000000,B00000000,B00000000,B00000000,B00000000,B00000000,B00001111,B11110000,B00000000,B00001111,
  B00000000,B00000000,B11110000,B11110000,B00000000,B00000000,B00000000,B00000000,B00000000,B00000000,B11110000,B11110000,B00000000,B00001111,
  B00000000,B00000000,B11110000,B11110000,B00000000,B00000000,B00000000,B00000000,B00000000,B00000000,B11110000,B11110000,B00000000,B00001111,
  B00000000,B00000000,B11110000,B11110000,B00000000,B00000000,B00000000,B00000000,B00000000,B00000000,B11110000,B11110000,B00000000,B00001111,
  B00000000,B00000000,B11110000,B11110000,B00000000,B00000000,B00000000,B00000000,B00000000,B00000000,B11110000,B11110000,B00000000,B00001111,
  B00000000,B00000000,B00001111,B00001111,B00000000,B00000000,B00000000,B00000000,B00000000,B00001111,B00001111,B00000000,B00000000,B00001111,
  B00000000,B00000000,B00001111,B00001111,B00000000,B00000000,B00000000,B00000000,B00000000,B00001111,B00001111,B00000000,B00000000,B00001111,
  B00000000,B00000000,B00001111,B00001111,B00000000,B00000000,B00000000,B00000000,B00000000,B00001111,B00001111,B00000000,B00000000,B00001111,
  B00000000,B00000000,B00001111,B00001111,B00000000,B00000000,B00000000,B00000000,B00000000,B00001111,B00001111,B00000000,B00000000,B00001111,
  B00001111,B11110000,B00000000,B11111111,B00001111,B11111111,B11111111,B11111111,B11111111,B00001111,B11110000,B00000000,B11111111,B00001111,
  B00001111,B11110000,B00000000,B11111111,B00001111,B11111111,B11111111,B11111111,B11111111,B00001111,B11110000,B00000000,B11111111,B00001111,
  B00001111,B11110000,B00000000,B11111111,B00001111,B11111111,B11111111,B11111111,B11111111,B00001111,B11110000,B00000000,B11111111,B00001111,
  B00001111,B11110000,B00000000,B11111111,B00001111,B11111111,B11111111,B11111111,B11111111,B00001111,B11110000,B00000000,B11111111,B00001111,
  B00001111,B00001111,B00000000,B00001111,B11111111,B00000000,B00000000,B00000000,B00001111,B11111111,B00000000,B00001111,B00001111,B00001111,
  B00001111,B00001111,B00000000,B00001111,B11111111,B00000000,B00000000,B00000000,B00001111,B11111111,B00000000,B00001111,B00001111,B00001111,
  B00001111,B00001111,B00000000,B00001111,B11111111,B00000000,B00000000,B00000000,B00001111,B11111111,B00000000,B00001111,B00001111,B00001111,
  B00001111,B00001111,B00000000,B00001111,B11111111,B00000000,B00000000,B00000000,B00001111,B11111111,B00000000,B00001111,B00001111,B00001111,
  B00000000,B11110000,B11110000,B11111111,B00000000,B00000000,B00000000,B00000000,B00000000,B00001111,B11110000,B11110000,B11110000,B00001111,
  B00000000,B11110000,B11110000,B11111111,B00000000,B00000000,B00000000,B00000000,B00000000,B00001111,B11110000,B11110000,B11110000,B00001111,
  B00000000,B11110000,B11110000,B11111111,B00000000,B00000000,B00000000,B00000000,B00000000,B00001111,B11110000,B11110000,B11110000,B00001111,
  B00000000,B11110000,B11110000,B11111111,B00000000,B00000000,B00000000,B00000000,B00000000,B00001111,B11110000,B11110000,B11110000,B00001111,
  B00000000,B00001111,B11111111,B11110000,B00000000,B00000000,B00000000,B00000000,B00000000,B00000000,B11111111,B11111111,B00000000,B00001111,
  B00000000,B00001111,B11111111,B11110000,B00000000,B00000000,B00000000,B00000000,B00000000,B00000000,B11111111,B11111111,B00000000,B00001111,
  B00000000,B00001111,B11111111,B11110000,B00000000,B00000000,B00000000,B00000000,B00000000,B00000000,B11111111,B11111111,B00000000,B00001111,
  B00000000,B00001111,B11111111,B11110000,B00000000,B00000000,B00000000,B00000000,B00000000,B00000000,B11111111,B11111111,B00000000,B00001111,
  B11111111,B00000000,B00001111,B00000000,B00000000,B00000000,B00000000,B00000000,B00000000,B00000000,B00001111,B00000000,B00001111,B11111111,
  B11111111,B00000000,B00001111,B00000000,B00000000,B00000000,B00000000,B00000000,B00000000,B00000000,B00001111,B00000000,B00001111,B11111111,
  B11111111,B00000000,B00001111,B00000000,B00000000,B00000000,B00000000,B00000000,B00000000,B00000000,B00001111,B00000000,B00001111,B11111111,
  B11111111,B00000000,B00001111,B00000000,B00000000,B00000000,B00000000,B00000000,B00000000,B00000000,B00001111,B00000000,B00001111,B11111111,
  B11110000,B11110000,B11111111,B00000000,B00000000,B00001111,B00000000,B00001111,B00000000,B00000000,B00001111,B11110000,B11110000,B11111111,
  B11110000,B11110000,B11111111,B00000000,B00000000,B00001111,B00000000,B00001111,B00000000,B00000000,B00001111,B11110000,B11110000,B11111111,
  B11110000,B11110000,B11111111,B00000000,B00000000,B00001111,B00000000,B00001111,B00000000,B00000000,B00001111,B11110000,B11110000,B11111111,
  B11110000,B11110000,B11111111,B00000000,B00000000,B00001111,B00000000,B00001111,B00000000,B00000000,B00001111,B11110000,B11110000,B11111111,
  B00001111,B00001111,B11110000,B00000000,B00000000,B00000000,B00000000,B00000000,B00000000,B00000000,B00000000,B11111111,B00001111,B00001111,
  B00001111,B00001111,B11110000,B00000000,B00000000,B00000000,B00000000,B00000000,B00000000,B00000000,B00000000,B11111111,B00001111,B00001111,
  B00001111,B00001111,B11110000,B00000000,B00000000,B00000000,B00000000,B00000000,B00000000,B00000000,B00000000,B11111111,B00001111,B00001111,
  B00001111,B00001111,B11110000,B00000000,B00000000,B00000000,B00000000,B00000000,B00000000,B00000000,B00000000,B11111111,B00001111,B00001111,
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

};
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
void loop() {

  current_time = millis();
  elapsed_time = current_time - sent_time;
  if (elapsed_time >= 28800000) { //Updates and Sends Climate Data every 8 hours
    sending_climate = true;
    server_send();
    Serial.println("Sent Climate Data To Server");
  }

  if ((WiFi.status() != WL_CONNECTED) && (current_time - previousMillis >=interval)) {
    Serial.println("Reconnecting to WiFi!");
    WiFi.disconnect();
    WiFi.reconnect();
    previousMillis = current_time;
  } 

  if (received_message) {
    draw_receiveddata();
    server_send();
    received_message = false;
  }
  if (get_buttons() == 1) { //Shows Clock Screen When Up Arrow is Pressed
    sending_activity = true;
    activity = 1;
    draw_clockdash();
    server_send();
    sending_activity = false;
    
  }
  if (get_buttons() == 2) { //Shows Water Dashboard
    sending_activity = true;
    activity = 2;
    draw_waterdash();
    server_send();
    sending_activity = false;
  }
  if (get_buttons() == 3) { //Shows Virtual Axol
    sending_activity = true;
    activity = 3;
    draw_axol();
    server_send();
    sending_activity = false;
  }
  if (get_buttons() == 4) { //Clear Display
    sending_activity = true;
    activity = 4;
    draw_system();
    server_send();
    sending_activity = false;
  }
  if (get_buttons() == 5) { //Clear Display
    sending_activity = true;
    activity = 5;
    display.clearDisplay();
    server_send();
    sending_activity = false;
  }
}


int get_buttons() { //Funtion returns int from 1 - 6

  /*
     1 - Up
     2 - Down
     3 - Right
     4 - Left
     5 - A
     6 - B
  */

  int touch_delay = 300;
  display.clearDisplay();

  if (!digitalRead(up)) {
    //delay(touch_delay);
    //Serial.println(up_cap);
    return 1;
    //display.clearDisplay();
  }

  else if (!digitalRead(down)) {
    //delay(touch_delay);
    return 2;
    //display.clearDisplay();
  }

  else if (!digitalRead(right)) {
    //delay(touch_delay);
    //display.clearDisplay();
    return 3;
  }

  else if (!digitalRead(left)) {
    //delay(touch_delay);
    return 4;
    //display.clearDisplay();
  }

  else if (!digitalRead(a)) {
    //delay(touch_delay);
    return 5;
    //display.clearDisplay();
  }
  else if (!digitalRead(b)) {
    //delay(touch_delay);
    return 6;
    //display.clearDisplay();
  }
}

void get_time() { //Functiuons queries server to get current time. Activates time screen.

  // Init and get the time
  configTime(gmtOffset_sec, daylightOffset_sec, ntpServer);
  struct tm timeinfo;
  if(!getLocalTime(&timeinfo)){
    Serial.println("Failed to obtain time");
    return;
  }

  //int num_month = month(timeinfo);
  //Serial.println(num_month);

  char buffer[80];  // Buffer to hold the formatted string. Adjust the size as needed.
  strftime(buffer, sizeof(buffer), "%Y-%m-%d %H:%M:%S", &timeinfo);
  formattedDate = String(buffer);
  //Serial.println(formattedDate);

  // Extract date
  int splitT = formattedDate.indexOf(" ");
  dayStamp = formattedDate.substring(0, splitT);
  Serial.print("DATE: ");
  //Serial.println(dayStamp);

  // Extract time
  timeStamp = formattedDate.substring(splitT + 1, formattedDate.length() - 3);
  Serial.print("HOUR: ");
  //Serial.println(timeStamp); 

}

void drawCS() { //Draws CS Logo
  display.clearDisplay();
  display.drawBitmap(
    (display.width()  - LOGO_WIDTH ) / 2,
    (display.height() - LOGO_HEIGHT) / 2,
    cs_logo_bmp, LOGO_WIDTH, LOGO_HEIGHT, 1);
  display.display();
  delay(1000);
}

void draw_axol() { //Draws Axol
  get_system_stats();
  
  display.clearDisplay();
  if (fill_percentage >= .5) {
    display.drawBitmap(
    (display.width()  - 108 ) / 2,
    (display.height() - 60) / 2,
    happy_axol_bmp, 108, 60, 1);
    display.display();
    
  } else {
    display.drawBitmap(
    (display.width()  - 125 ) / 2,
    (display.height() - 60) / 2,
    sad_axol_bmp, 125, 60, 1);
    display.display();
  }
  
  delay(5000);
  draw_maindash();
  
}

void draw_weather_icon(const unsigned char icon[], int width, int height) {
  display.drawBitmap(
    (display.width() - width),
    (display.height() - height),
    icon, width, height, 1);
}

void draw_waterdash () { //Function Draws Dashboard with loction, weather and time information.

  get_system_stats();
  
  int16_t x1;
  int16_t y1;
  uint16_t width;
  uint16_t height;  
  
  //Serial.println(remaining_average);
  display.clearDisplay();
  display.setTextSize(2);
  display.setTextColor(WHITE);
  display.setCursor(0, 0);
  display.print("Reservas: ");
  display.print(fill_percentage * 100);
  display.println(" %");
  display.setTextSize(1);
  display.println("");
  display.print(avail_liters);
  display.print("/");
  display.print(avail_storage);
  display.println(" L ");
  display.println("Displonibles");

  //water quality dashboard!!!!!!!!!!!!!!!!!
  
  /*if (remaining_average >= water_goal) {
    draw_water_icon(happy_drop_bmp, WWIDTH, WHEIGHT);
  }
  if (remaining_average <= water_goal) {
    draw_water_icon(sad_drop_bmp, WWIDTH, WHEIGHT);
  } */
  display.display();

  delay(5000);
  draw_maindash();
}

void draw_system() {
  int16_t x1;
  int16_t y1;
  uint16_t width;
  uint16_t height;  
  //Serial.println(remaining_average);
  display.clearDisplay();
  display.setTextSize(2);
  display.setTextColor(WHITE);
  display.setCursor(0, 0);
  display.println("Sensores");
  display.println("");
  display.setTextSize(1.5);
  display.print("Cubetas: ");
  display.println(buckets);
  display.print("Tanques: ");
  display.println(tanks);
  display.print("Calidad: ");
  display.println(quality);
  display.print("Ambiente: ");
  display.println(envs);

  display.display();

  delay(5000);
  draw_maindash();
  
}

void draw_receiveddata() {

  display.clearDisplay();
  for (int16_t i = max(display.width(), display.height()) / 2; i > 0; i -= 3) {
    // The INVERSE color is used so circles alternate white/black
    display.fillCircle(display.width() / 2, display.height() / 2, i, SSD1306_INVERSE);
    display.display(); // Update screen with each newly-drawn circle
    delay(1);
  }

  draw_maindash();

}

void draw_maindash() { //Turn Screen Off
  display.clearDisplay();
  display.display();
}

void draw_clockdash() {

  get_time();
  get_complete_weather();

  int16_t x1;
  int16_t y1;
  uint16_t width;
  uint16_t height;

  display.clearDisplay();
  display.setTextSize(2.5);
  display.setTextColor(WHITE);
  //Gents Center for Date
  display.getTextBounds(timeStamp, 0, 0, &x1, &y1, &width, &height);
  display.setCursor(0, 5);
  display.println(timeStamp);

  display.setTextSize(.9);
  display.getTextBounds(dayStamp, 0, 0, &x1, &y1, &width, &height);
  display.setCursor(0, 25);
  display.println(dayStamp);

  display.setTextSize(0);
  display.getTextBounds(city_name, 0, 0, &x1, &y1, &width, &height);
  display.setCursor(0, 55);
  display.println(city_name);

  int d_temp = round(main_temp - 272.15);
  int d_max = round(main_temp_max - 272.15);
  int d_min = round(main_temp_min - 272.15);

  display.setTextSize(2);
  String display_temp = String(d_temp) + "C" ;
  display.getTextBounds(display_temp, 0, 0, &x1, &y1, &width, &height);
  display.setCursor(SCREEN_WIDTH - width, 5);
  display.println(display_temp);

  display.setTextSize(.9);
  String display_range = String(d_min) + "C / " + String(d_max) + "C";
  display.getTextBounds(display_range, 0, 0, &x1, &y1, &width, &height);
  display.setCursor(SCREEN_WIDTH - width, 25);
  display.println(display_range);

  if ((String(weather_0_icon) == "04d") || (String(weather_0_icon) == "04n") || (String(weather_0_icon) == "03n") || (String(weather_0_icon) == "03d") ) { //Clouds
    draw_weather_icon(cloud_bmp, 30, 16);
  } else if ((String(weather_0_icon) == "01d") || (String(weather_0_icon) == "01n") || (String(weather_0_icon) == "02n") || (String(weather_0_icon) == "02d")) { //Sun
    draw_weather_icon(sun_bmp, 30, 30);
  } else if ((String(weather_0_icon) == "09d") || (String(weather_0_icon) == "09n") || (String(weather_0_icon) == "10d") || (String(weather_0_icon) == "10n") ) { //Rain
    draw_weather_icon(rain_bmp, 30, 25);
  } else if ((String(weather_0_icon) == "11d") || (String(weather_0_icon) == "11n")) { //Storm
    draw_weather_icon(storm_bmp, 30, 30);
  } else if ((String(weather_0_icon) == "13d") || (String(weather_0_icon) == "13n")) { //Snow
    draw_weather_icon(snow_bmp, 30, 30);
  } else { //Could be mist or other conditions.

  }

  display.display();
  delay(3500);

  draw_maindash();

}
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

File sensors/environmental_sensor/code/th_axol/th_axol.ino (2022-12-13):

/*
  
   █████╗ ██╗  ██╗ ██████╗ ██╗     
  ██╔══██╗╚██╗██╔╝██╔═══██╗██║     
  ███████║ ╚███╔╝ ██║   ██║██║     
  ██╔══██║ ██╔██╗ ██║   ██║██║     
  ██║  ██║██╔╝ ██╗╚██████╔╝███████╗
  ╚═╝  ╚═╝╚═╝  ╚═╝ ╚═════╝ ╚══════╝

  Axol sensing system. 

  ╔═╗┬┌┬┐┬ ┬  ╔═╗┌─┐┬┌─┐┌┐┌┌─┐┌─┐       ╔╦╗╦╔╦╗  ╔╦╗┌─┐┌┬┐┬┌─┐  ╦  ┌─┐┌┐
  ║  │ │ └┬┘  ╚═╗│  │├┤ ││││  ├┤   ───  ║║║║ ║   ║║║├┤  │││├─┤  ║  ├─┤├┴┐
  ╚═╝┴ ┴  ┴   ╚═╝└─┘┴└─┘┘└┘└─┘└─┘       ╩ ╩╩ ╩   ╩ ╩└─┘─┴┘┴┴ ┴  ╩═╝┴ ┴└─┘

                                 .|
                                | |
                                |'|            ._____
                        ___    |  |            |.   |' .---"|
                _    .-'   '-. |  |     .--'|  ||   | _|    |
             .-'|  _.|  |    ||   '-__  |   |  |    ||      |
             |' | |.    |    ||       | |   |  |    ||      |
          ___|  '-'     '    ""       '-'   '-.'    '`      |____

   Code for temperature and humidity sensor for the Axol sensing system. 
   The code runs on an ESP32 chip along with a STHx sensor module. 

   Andres Rico - aricom@mit.edu
  
 */

#include <Arduino.h>
#include <SensirionI2CSht4x.h>
#include <WiFi.h>
#include <esp_now.h>
#include <esp_wifi.h>
#include <Wire.h>
#include <vl53l4cx_class.h>
#include <string.h>
#include <stdlib.h>
#include <stdio.h>
#include <stdint.h>
#include <assert.h>
#include <stdlib.h>

#define DEV_I2C Wire
#define uS_TO_S_FACTOR 1000000  /* Conversion factor for micro seconds to seconds */
#define TIME_TO_SLEEP  10        /* Time ESP32 will go to sleep (in seconds) */

uint8_t broadcastAddress[] = {0xXX, 0xXX, 0xXX, 0xXX, 0xXX, 0xXX}; //Replace XX with Paired Homehub Address MAC Address digits. 
constexpr char WIFI_SSID[] = ""; //Input WIFI network name.

int32_t getWiFiChannel(const char *ssid) { //Function for 

  if (int32_t n = WiFi.scanNetworks()) {
    for (uint8_t i = 0; i < n; i++) {
      if (!strcmp(ssid, WiFi.SSID(i).c_str())) {
        return WiFi.channel(i);
      }
    }
  }

  return 0;
}

typedef struct struct_message { //Structure of sensor data packet that is sent to the HomeHub. 
  char id[50];    //Sensor MAC Address
  int type;       //Type of sensor. -> Temperature/Humidity = 3
  int temp;       //Current temperature
  int humidity;   //Current humidity
} struct_message;

struct_message myData;

String address = WiFi.macAddress(); //Fetch sensor MAC Address. 
char mac_add[50];

int attempts = 0;

void OnDataSent(const uint8_t *mac_addr, esp_now_send_status_t status) {
  Serial.print("\r\nLast Packet Send Status:\t");
  Serial.println(status == ESP_NOW_SEND_SUCCESS ? "Delivery Success" : "Delivery Fail");

}


SensirionI2CSht4x sht4x;

int sensPin = 4; /Pin for powering sensor from ESP32 GPIO. 
float temperature;
float humidity;

void getHumTemp() {
  
  uint16_t error;
  char errorMessage[256];

  delay(1000);

  error = sht4x.measureHighPrecision(temperature, humidity);
  
  if (error) {
    Serial.print("Error trying to execute measureHighPrecision(): ");
    errorToString(error, errorMessage, 256);
    Serial.println(errorMessage);
  } else {
    Serial.print("Temperature:");
    Serial.print(temperature);
    Serial.print("\t");
    Serial.print("Humidity:");
    Serial.println(humidity);
  }

}

void setup() {
  // put your setup code here, to run once:
  Serial.begin(115200);
  pinMode(sensPin, OUTPUT);
  //pinMode(lightPin, INPUT);
  digitalWrite(sensPin, HIGH);

  Wire.begin();

  uint16_t error;
  char errorMessage[256];

  sht4x.begin(Wire);

  getHumTemp();
  address.toCharArray(mac_add, 50);
  WiFi.mode(WIFI_STA);
  int32_t wifi_channel = getWiFiChannel(WIFI_SSID);
  strcpy(myData.id, mac_add);
  myData.type = 3; //Id 2 = Tank Level sensor.
  myData.temp = temperature;
  myData.humidity = humidity;

  Serial.println(myData.id);

  //WiFi.printDiag(Serial); // Uncomment to verify channel number before
  esp_wifi_set_promiscuous(true);
  esp_wifi_set_channel(wifi_channel, WIFI_SECOND_CHAN_NONE);
  esp_wifi_set_promiscuous(false);
  //WiFi.printDiag(Serial); // Uncomment to verify channel change after

  //Serial.println(WiFi.macAddress());
  // Init ESP-NOW
  esp_now_init(); //Start ESP now communication. 
  
  esp_now_register_send_cb(OnDataSent); // get the status of Trasnmitted packet

  // Register peer
  esp_now_peer_info_t peerInfo;
  memcpy(peerInfo.peer_addr, broadcastAddress, 6);
  peerInfo.encrypt = false;

  // Add peer
  esp_now_add_peer(&peerInfo); //Loof for esp now peer. 

  // Send message via ESP-NOW
  esp_err_t result = esp_now_send(broadcastAddress, (uint8_t *) &myData, sizeof(myData));

  esp_sleep_enable_timer_wakeup(43200000000) ; //Time in uS -> Reports Twice a day. 

  esp_wifi_stop(); //Shut down wifi before going to sleep. 

  esp_deep_sleep_start(); //Go into Deep Sleep

}

void loop() {
  // put your main code here, to run repeatedly:
}

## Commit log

2022-06-08 added bucket flip board files
2022-07-26 esp32 based bucket flip added
2022-07-26 added esp32 mini homehub design
2022-08-12 made new pcb design for using esp32 in sleep mode
2022-10-31 esp32 bucket low power schematic added
2022-11-23 new bucket sensor files
2022-11-23 added new environmental sensor files
    [temp_hum_lid.dxf]
2022-11-23 added tank sensor files
    [TankCover.dxf, tank_case.stl]
2022-11-23 added water quality sensors.
2022-11-23 modified bucket sensor files
2022-12-13 added new tank sensor board
2022-12-13 added push button based design
2022-12-13 changed hardware name on main structure
    [TankCover.dxf, tank_case.stl, temp_hum_lid.dxf]
2023-01-19 added temp/hum gerber files
2023-01-19 added water quality gerber files.
2023-01-19 added bucket sensor gerber files.
2023-01-19 added homehub gerber file
2023-01-26 updated bucket case files
    [bucket_case.stl, bucket_lid.dxf]
2023-01-26 added env sensors.
    [env_case.stl]
2023-01-26 added homehub case update
    [hh_lid.stl, hhcase.stl]
2023-02-01 added new case files
    [button.stl, hhcase.stl]
2023-02-08 added bucket sensor code.
2023-02-08 added water quality sensor program
    [buoy_air_cavity.stl, buoy_balast.stl, buoy_lid.dxf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]
2023-02-08 added th sensor program.
2023-02-08 added tank sensor code.
2023-02-23 fixed code for water quality sensor
    [quality_axol.ino]
2023-02-28 added water quality case files
    [buoy_lid_short.stl, buoy_plug.stl, hh_case_screen.dxf]
2023-02-28 Added LED difuser part
    [LED_Diffuser.stl]
2023-08-10 bucket sensor board files
2023-08-10 fixed hh board files
    [packaging.stl]
2023-08-10 restructured homehub outside of sensors directory
    [LED_Diffuser.stl, button.stl, hh_case_screen.dxf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]
2023-08-10 added user manual
    [packaging.stl]
2023-08-10 added links to register devices and to check data.
2023-08-10 added sensor and homehub descriptions in readme.
2023-08-11 added comments to bucket sensor code
2023-08-11 fixed data type comment
    [bucket_axol.ino]
2023-08-11 added comments to environmental sensor.
2023-08-11 added comments to tank sensor.
2023-08-11 adding temp hum sensor comments
2023-08-11 added comments to quality sensor.
2023-08-11 added axol ascii
    [LED_Diffuser.stl, button.stl, hh_case_screen.dxf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]
2023-08-11 added specific sensor images
2023-08-11 added bucket.md
2023-08-11 added link to bucket sensor page
2023-08-11 added readmes for all sensors
2023-08-11 added bom bucket
2023-08-11 added quality bom
2023-08-11 added tank bom
2023-08-11 added pcb diagram images
2023-08-11 added env bom and readme
2023-08-11 modified main sensor images
2023-08-25 added bucket schematic image
2023-08-25 added tank sensor schematic and board images
2023-08-25 added quality schematic and board
2023-08-25 added hh schematic and board images
2023-08-25 added env sensor schematic and board
2023-08-29 addded programming to bucket
2024-07-11 fixed NTP client time issue
    [cs_homehub.ino]
